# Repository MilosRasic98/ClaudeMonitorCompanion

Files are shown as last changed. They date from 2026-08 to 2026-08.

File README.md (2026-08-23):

# Claude Monitor Companion








A desk mascot that shows what Claude Code is doing.

<p align="center">
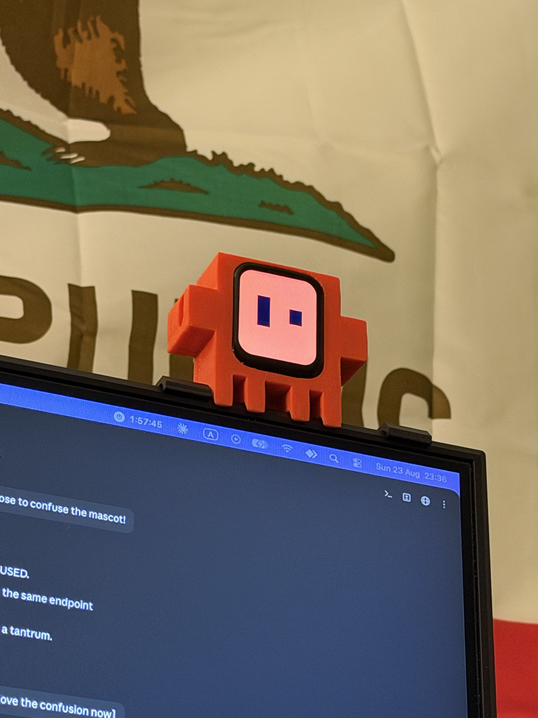
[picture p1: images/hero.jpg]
The mascot hooked over the top of a monitor, eyes lit
  
</p>

A Waveshare ESP32-S3-Touch-LCD-1.69 sits in a 3D-printed shell shaped like the Claude
mascot — the chunky pixel-art crab. The LCD is set into the middle as its face: a flat
orange field with two black bar eyes. The eyes doze when nothing is happening, get bored
when you wander off, focus while Claude works, and snap into a `><` grin the moment Claude
needs you. Hit the five-hour usage limit and the whole screen goes red with a blinking
exclamation mark. A mechanical bell rings for anything that wants your attention.

Claude Code hooks POST bare event names at the board over your LAN. The board decides how it
feels about them.

<p align="center">
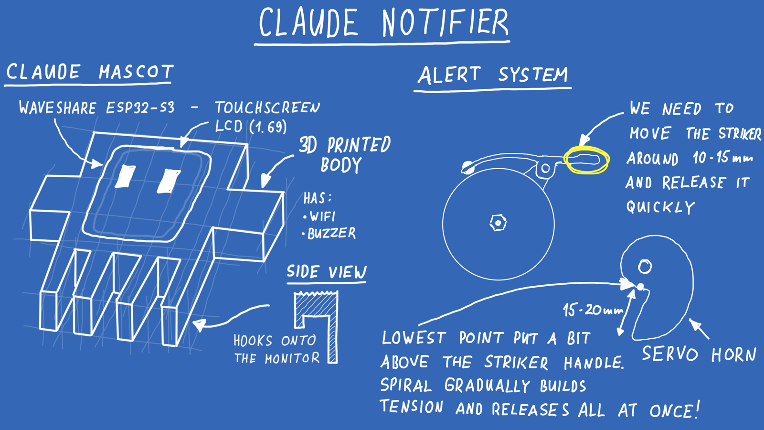
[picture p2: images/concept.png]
Concept sketch of the mascot and the bell striker mechanism
  
</p>

## What it does

### Eight moods

Driven partly by events from your computer, partly by time the board tracks itself.

| Mood | When |
|---|---|
| `SLEEPING` | nothing for ~30 minutes |
| `CHILL` | recent activity, nothing running |
| `BORED` | no new prompt for ~5 minutes |
| `WORKING` | between your prompt and Claude finishing |
| `EXCITED` | Claude needs you, or a turn just finished |
| `CONFUSED` | something failed |
| `ANGRY` | you poked it five times in four seconds |
| `LIMIT` | usage limit reached — red field, blinking `!` |

| | | | |
|:---:|:---:|:---:|:---:|
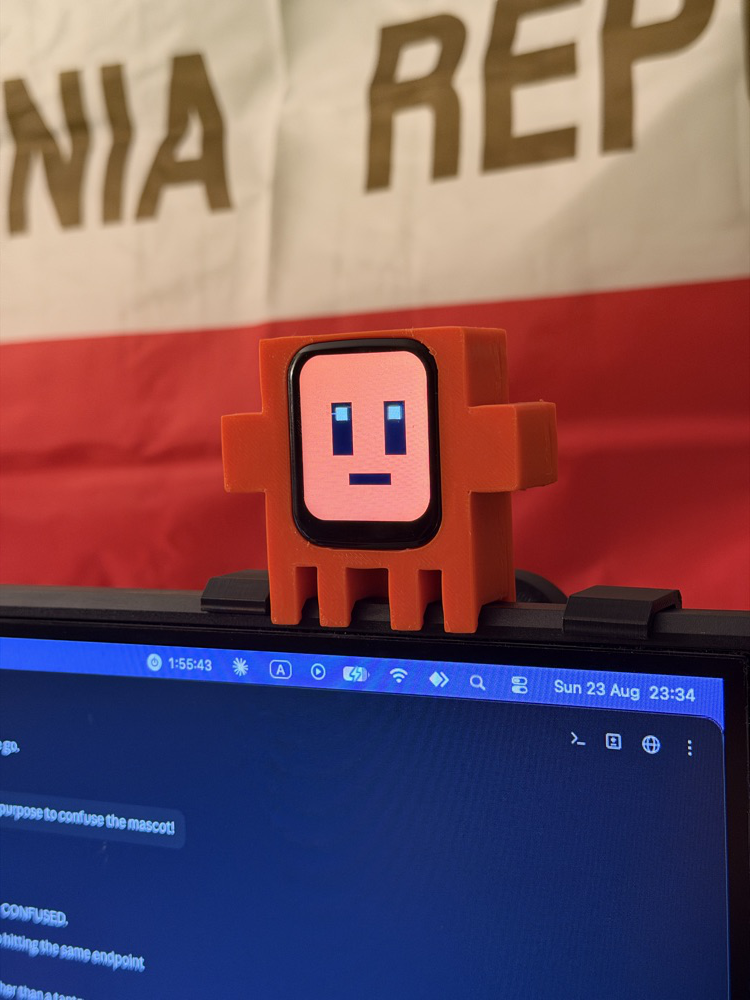
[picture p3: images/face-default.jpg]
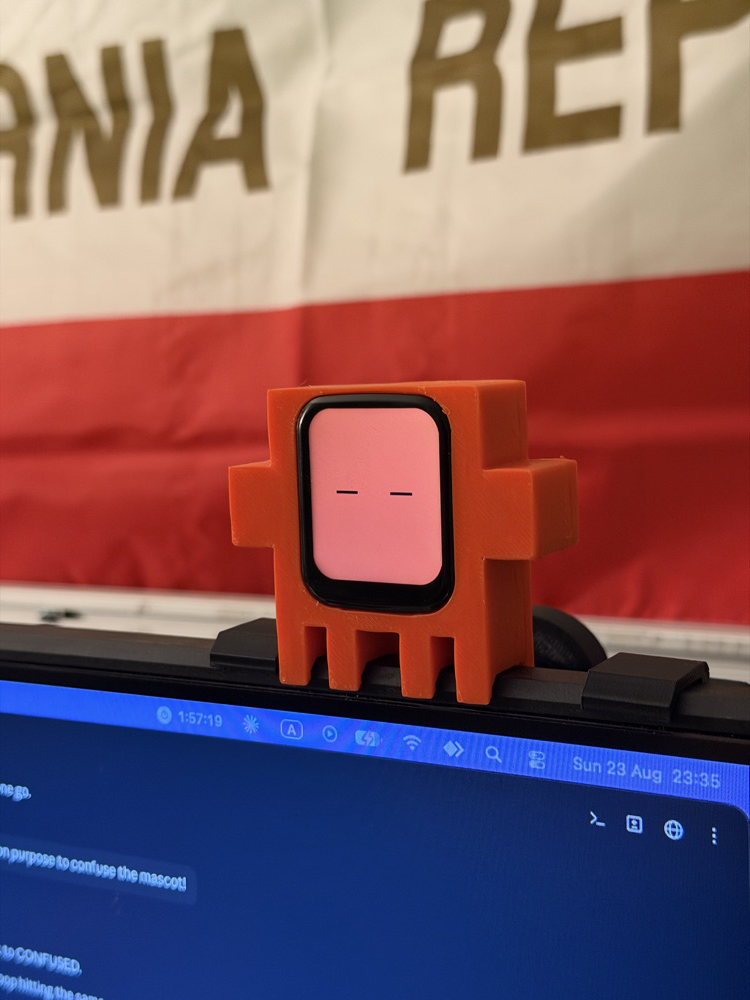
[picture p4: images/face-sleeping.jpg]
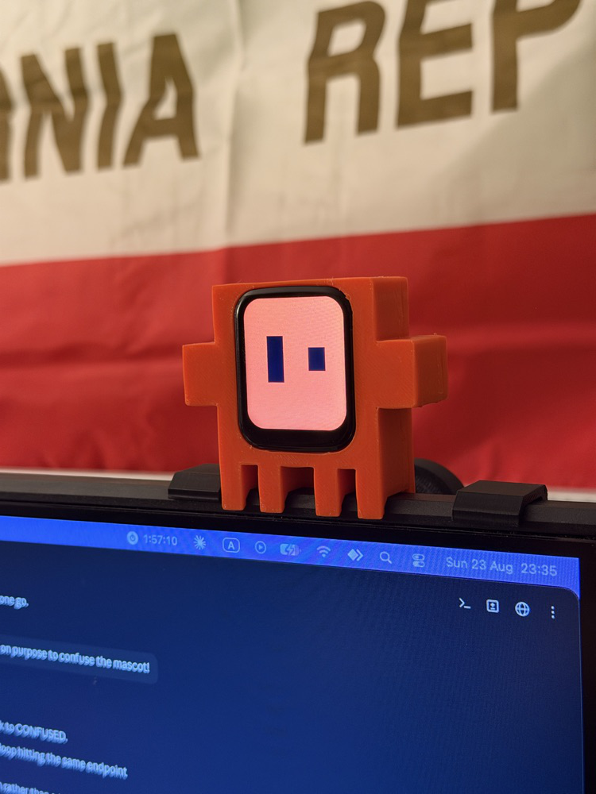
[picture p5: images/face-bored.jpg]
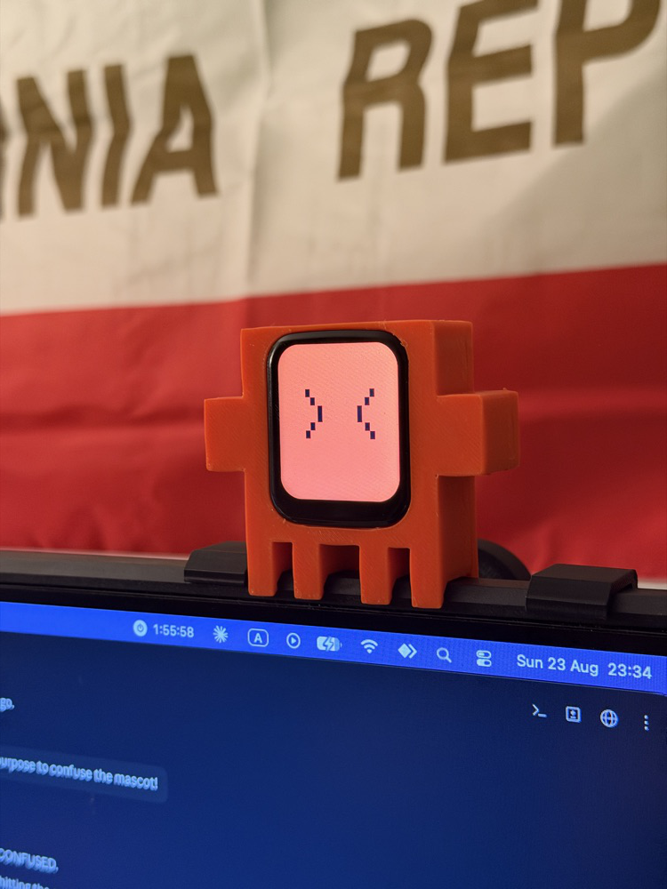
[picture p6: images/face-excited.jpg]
|  |  |  |  |
| **Chill** — resting | **Sleeping** — lids shut, breathing | **Bored** — lids low, gaze adrift | **Excited** — the `><` grin |
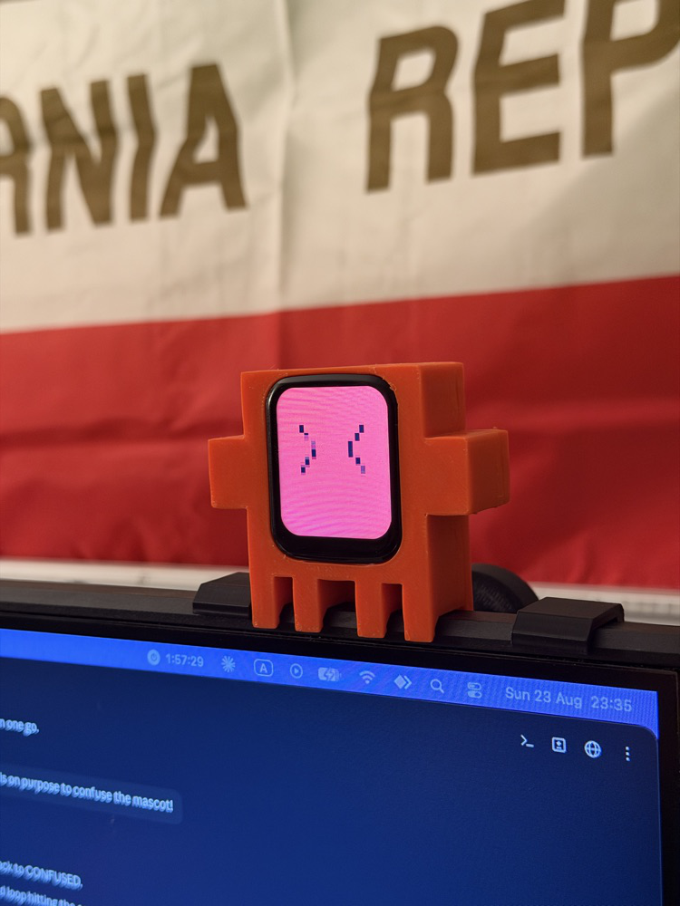
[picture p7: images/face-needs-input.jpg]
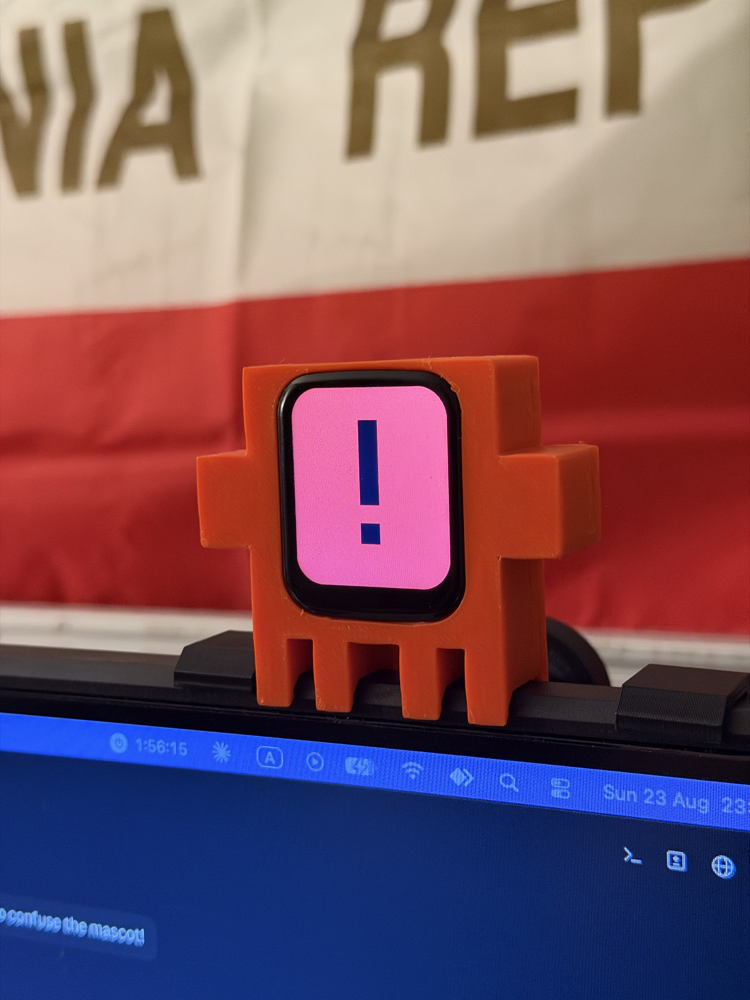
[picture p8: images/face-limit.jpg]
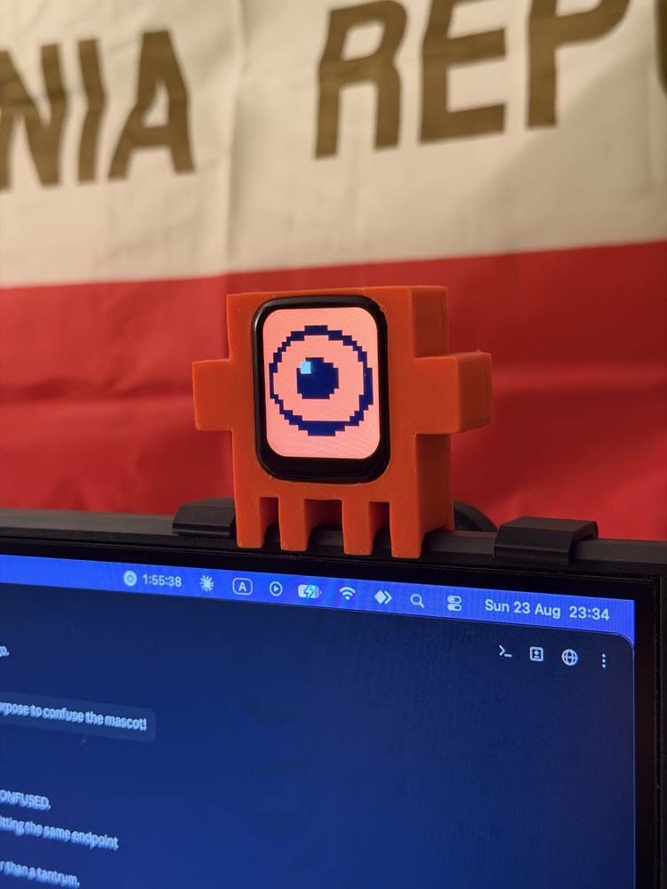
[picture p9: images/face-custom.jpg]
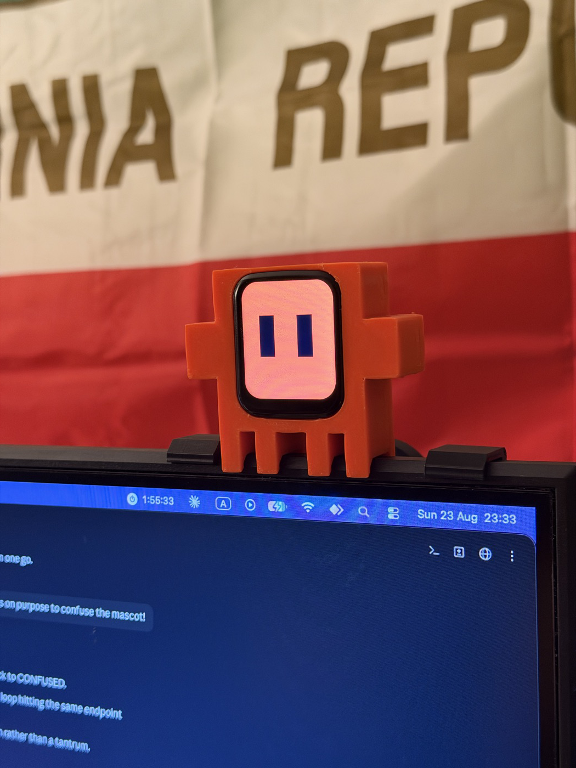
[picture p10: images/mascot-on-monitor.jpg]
|  |  |  |  |
| **Needs input** — red until you answer | **Limit reached** — blinking `!` | **A face you drew yourself** | Perched on the monitor |

Two of those moods — `BORED` and `SLEEPING` — are the *absence* of events. No hook can fire
to say "nothing has happened for five minutes", so the board keeps its own clock. A useful
side effect: the face keeps behaving correctly when the computer sleeps, the Wi-Fi drops, or
Claude Code is closed.

### Five faces, plus four of your own

Taken from the printed mascot's variants: bare eyes, a `><` grin, round spectacles with a
grill mouth, chunky pixel glasses with a smile, and deal-with-it shades with a moustache.
Swipe sideways to cycle them.

| | | |
|:---:|:---:|:---:|
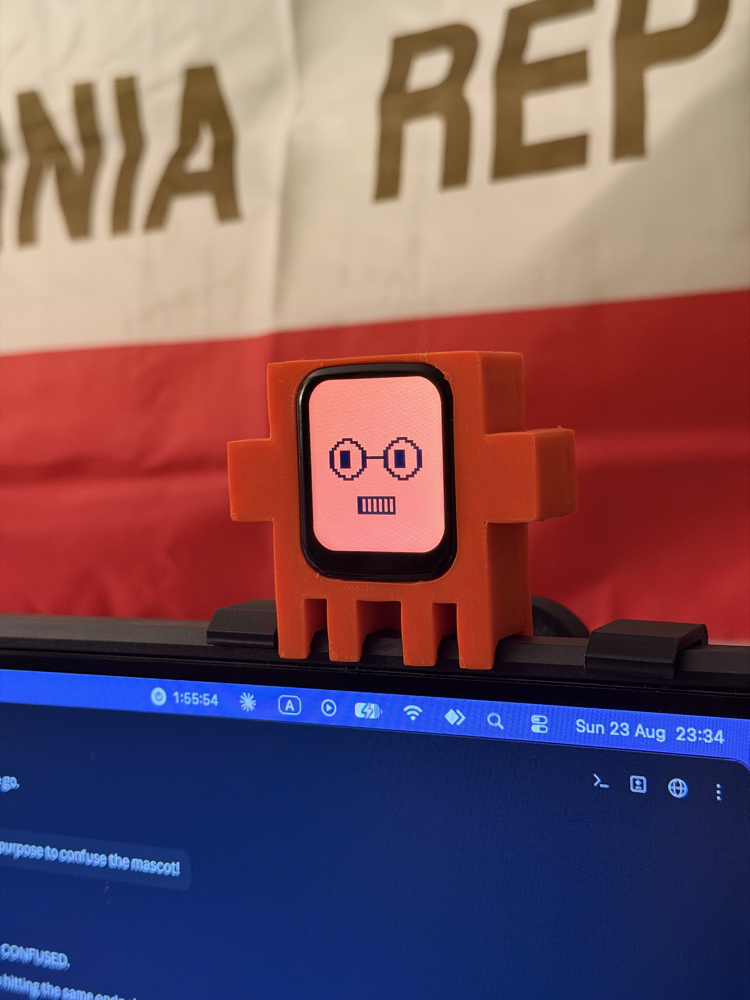
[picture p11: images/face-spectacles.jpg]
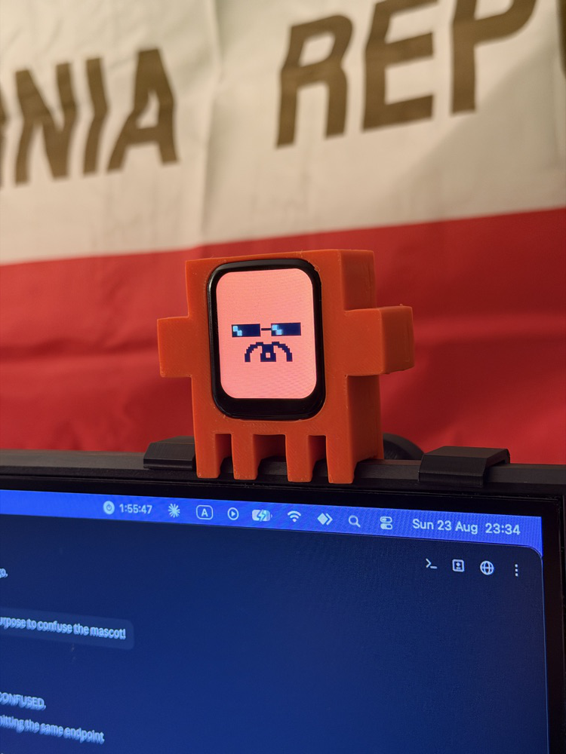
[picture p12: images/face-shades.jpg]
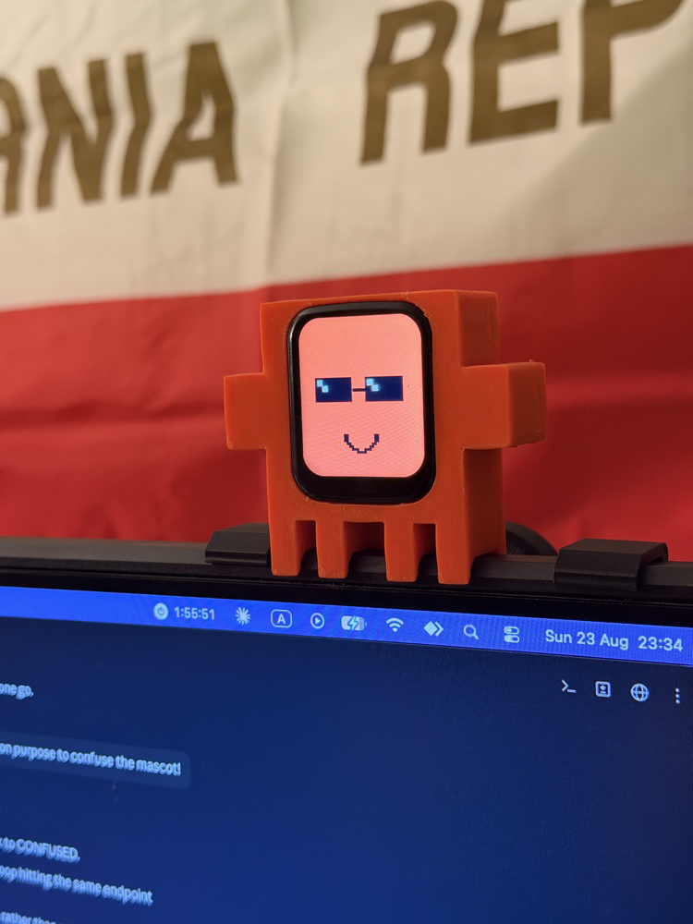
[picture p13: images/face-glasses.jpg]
|  |  |  |
| Round spectacles, grill mouth | Shades and a moustache | Pixel glasses and a smile |

The settings page has a pixel editor. Draw a face on a 24×28 grid, give it a second frame if
you want it to blink, and it joins the rotation — stored in flash, so it survives a reboot.
Drawn faces get the same mood vocabulary as the built-in ones by *translating* within the
frame: the working sweep, the bored droop and the excited bounce all still work.

### Four screens

Swipe up or down for the mascot, a ring gauge showing how much of your five-hour limit is
used and how long until it resets, the same for the seven-day all-models limit, and a plain
stats screen.

### Sound

An optional mechanical bell striker rings for anything that wants your attention, and the
onboard piezo buzzes twice when a turn finishes. Which of bell, buzzer or both fires for each
cue is configurable.

### A settings page, served by the board

Forty-six settings — sound, face geometry, mood thresholds, brightness, Wi-Fi — all editable
from a phone. Flash once and you never open the firmware again. Get the Wi-Fi wrong and the
board hosts its own access point so you can fix it.

## The hardware

<p align="center">
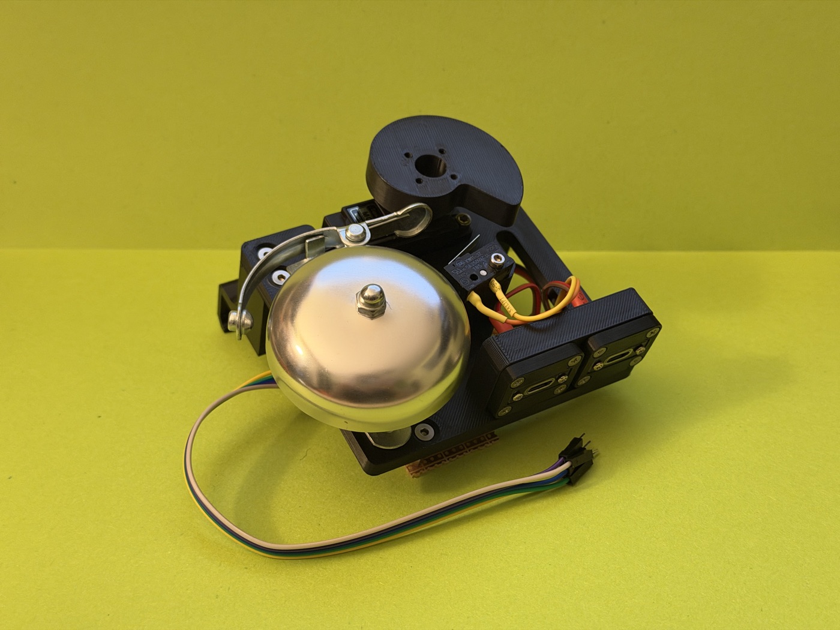
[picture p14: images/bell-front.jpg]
The bell striker assembly
  
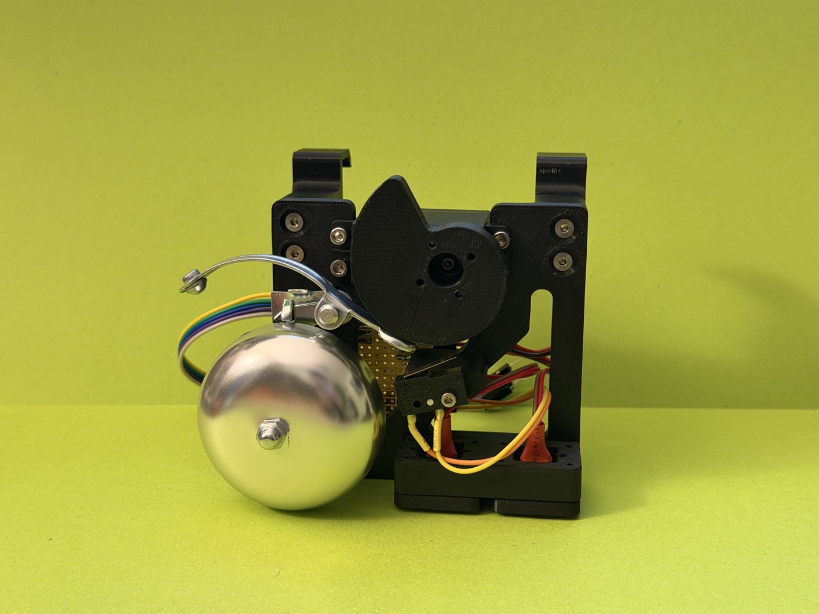
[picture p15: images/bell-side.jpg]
Side view of the servo, cam and bell
  
</p>

The bell is a continuous-rotation servo turning a cam against a desk bell's striker. The cam
gradually builds tension and releases it all at once. A microswitch counts the rings, so the
firmware can stop after a set number of strikes rather than guessing at a duration.

<p align="center">
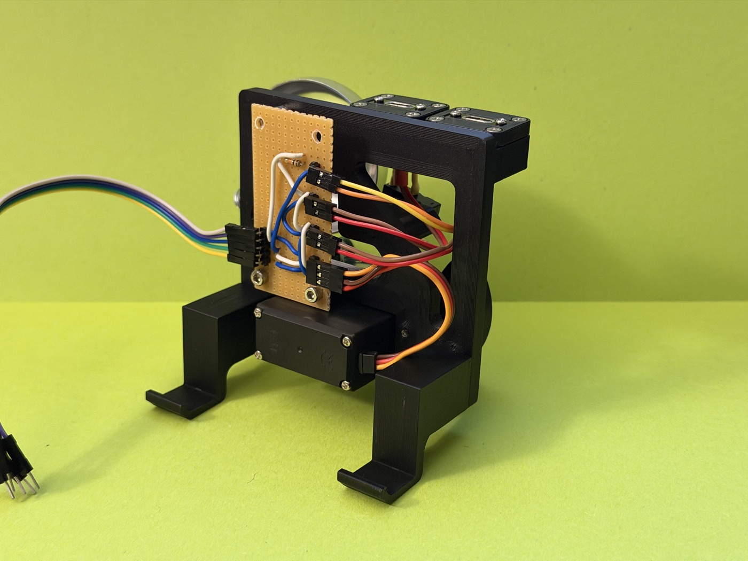
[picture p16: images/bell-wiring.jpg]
Perfboard wiring for the servo and switch
  
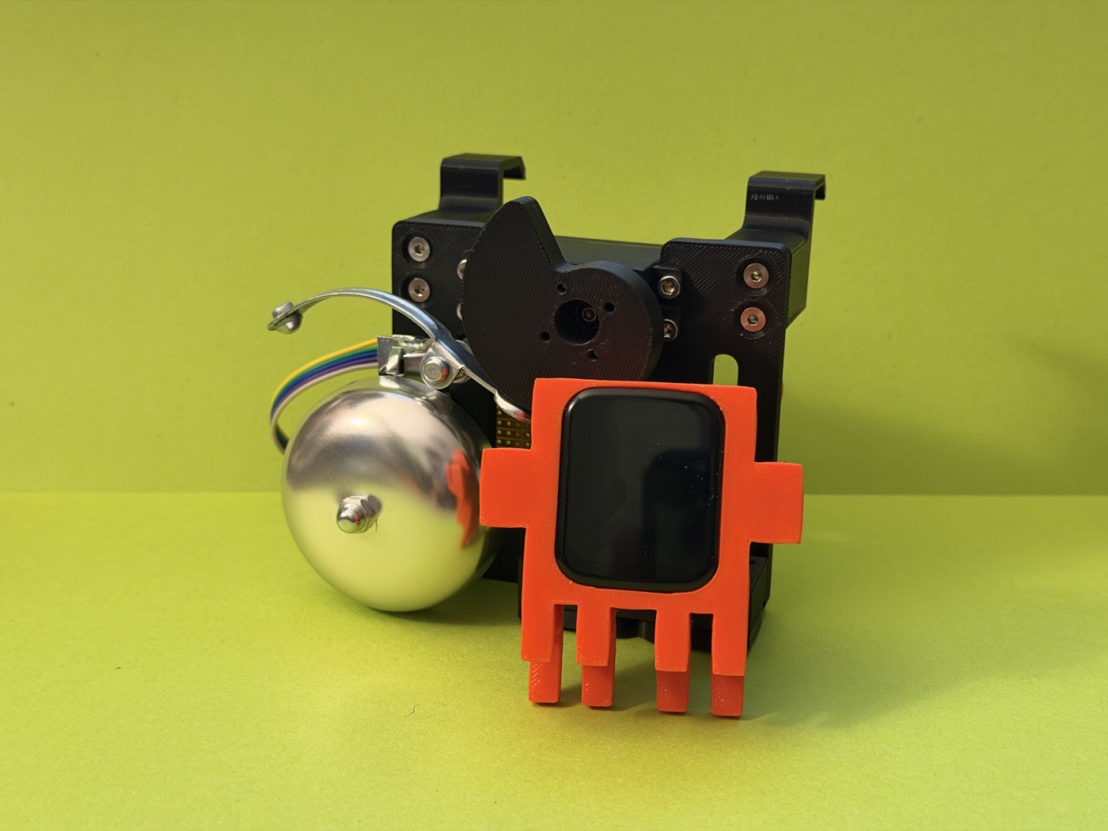
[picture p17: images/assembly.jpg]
Shell and bell mechanism assembled together
  
</p>

| Signal | Pin |
|---|---|
| Servo | GPIO 18 — 50 Hz PWM, 2500 µs runs, 1500 µs stops |
| Microswitch | GPIO 17 — COM to 3V3, NO to the pin, 10 kΩ pulldown |

Both are configurable at runtime; setting either to `-1` disables that half. The bell is
entirely optional — everything else works without it.

Full wiring diagram: **[Hardware/Schematics.png](Hardware/Schematics.png)**. Pin map, measured
performance figures and the traps worth knowing: **[Code/docs/HARDWARE.md](Code/docs/HARDWARE.md)**.

### Bill of materials

| # | Product name | Manufacturer | Qty | Farnell | Newark |
|---|---|---|---|---|---|
| 1 | Continuous servo | Adafruit | 1 | 2816371 | 85W1247 |
| 2 | Microswitch | Multicomp Pro | 1 | 3553972 | 84AH0093 |

Everything else, no particular source needed:

| # | Name | Description |
|---|---|---|
| 1 | Waveshare ESP32-S3 Touchscreen 1.69 | https://www.waveshare.com/wiki/ESP32-S3-Touch-LCD-1.69 |
| 2 | Mechanical bell | |
| 3 | 3D printing filament | |
| 4 | M3 and M2 screws | |
| 5 | Wires and perfboard | |

## The 3D-printed shell

<p align="center">
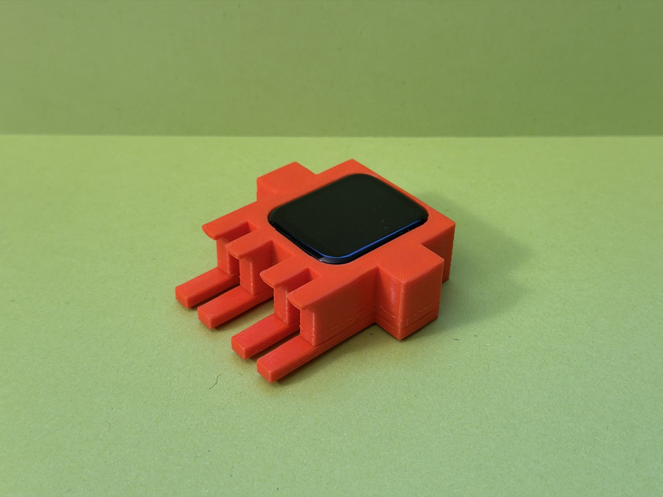
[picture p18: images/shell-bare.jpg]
The bare orange shell
  
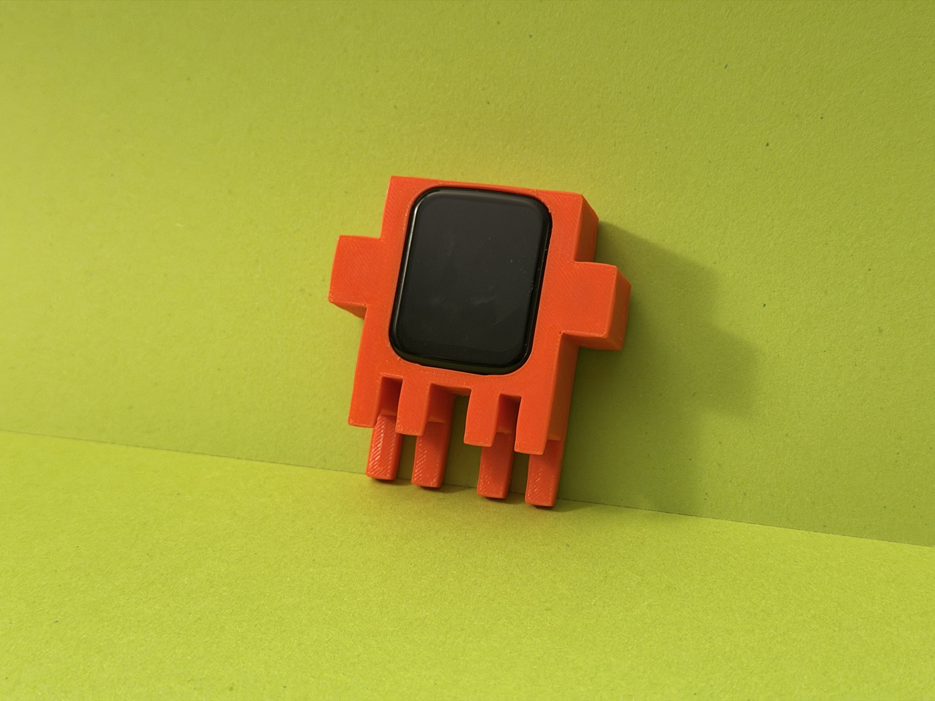
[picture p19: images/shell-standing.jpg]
The shell standing up
  
</p>

Print files are in [`CAD/`](CAD) as both 3MF and STEP: the front and back shells, the monitor
hook, the bell plate, the bell cam and a USB-C plate. Orange for the body, black for the bell
frame.

## How it talks to Claude Code

Claude Code has a feature called **hooks**: entries in its settings file that run a command
when something happens. The command here is literally `curl`.

```json
{
  "type": "command",
  "command": "curl",
  "args": ["-s", "-m", "2", "-X", "POST",
           "-H", "Authorization: Bearer <token>",
           "http://<board-ip>/e/turn_finished"],
  "async": true
}
```

That is the entire mechanism. There are twelve of these and they differ only in the last word
of the URL. Because the event name rides in the URL path there is no body to build, quote or
escape — so no script is needed, and the same config works byte-for-byte on macOS, Windows
and Linux.

**[HOW-IT-WORKS.md](HOW-IT-WORKS.md)** explains the whole thing in a page.

## Platforms

Hooks work everywhere Claude Code runs, including the desktop app: moods, faces, sounds and
the usage-limit alert all come from them.

The two ring gauges need the **CLI**, and specifically the session you are working in. They
are fed by the status line, which the desktop app never runs, and whose figures only refresh
when a session makes API calls — so an idle CLI window parked beside the app reports a frozen
number rather than a live one. The board notices and labels it.

Hooks are exec form and identical on macOS, Linux and Windows. The status line needs a
per-platform script, and the generator emits the right one — Python on Unix, PowerShell on
Windows, where it needs nothing that Windows does not already ship.

## Repository layout

| | |
|---|---|
| [`Code/`](Code) | Firmware. PlatformIO + Arduino, ESP32-S3. Start at [Code/README.md](Code/README.md) |
| [`CAD/`](CAD) | Printable parts, 3MF and STEP |
| [`Hardware/`](Hardware) | Wiring schematic |
| [`images/`](images) | Build and result photos |
| [`HOW-IT-WORKS.md`](HOW-IT-WORKS.md) | How the board and Claude Code actually talk, in a page |

## Quick start

```bash
cd Code
cp include/secrets.h.example include/secrets.h   # first-boot Wi-Fi defaults
pio run -t upload
pio device monitor                               # prints the board's IP
```

Then open that IP in a browser to configure everything else, and wire up the Claude Code
hooks:

```bash
python3 tools/gen_hooks.py <board-ip> <your-token>
```

Merge the output into `~/.claude/settings.json`.
[`Code/docs/settings.example.json`](Code/docs/settings.example.json) shows what that output
looks like, with placeholders in place of the address and token. The full walkthrough,
including why the hook config is shaped the way it is, is in [Code/README.md](Code/README.md).

## Notes on the build

No external libraries. No LVGL, no async web server, no JSON library — just the Arduino core
and the ESP-IDF components it already ships. The face is drawn as quantised rectangles
straight onto the panel, which is both the correct pixel-art look and fast: 62 fps at under
5% of the frame budget.

## Licence

GPL-3.0. See [LICENSE](LICENSE).

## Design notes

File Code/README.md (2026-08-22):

# Claude Monitor Companion

A desk mascot that shows what Claude Code is doing.

A Waveshare ESP32-S3-Touch-LCD-1.69 sits in a 3D-printed shell shaped like the Claude
mascot — the chunky pixel-art crab. The LCD is set into the middle as its face: a flat
orange field with two black bar eyes. The eyes doze when nothing is happening, get bored
when you wander off, focus while Claude works, and snap into a `><` grin the moment Claude
needs you.

Claude Code hooks POST bare event names at the board over the LAN. The board decides how it
feels about them.

- [docs/SPEC.md](docs/SPEC.md) — design, mood engine, open questions
- [docs/HARDWARE.md](docs/HARDWARE.md) — pin map, measured numbers, traps

## Setup

You flash once. After that everything is configured from the board's own web page — Wi-Fi
included — so there is never a second reason to open the firmware.

### 1. Credentials

```bash
cp include/secrets.h.example include/secrets.h
```

Fill in `WIFI_SSID` and `WIFI_PASS`, and set `NOTIFY_TOKEN` to any random string. These are
only the **first-boot defaults**: they are copied into NVS on first run and everything after
that is edited from the settings page. `include/secrets.h` is gitignored.

If you get them wrong, nothing is lost. After four failed joins the board gives up on your
network and hosts its own open access point called `<hostname>-setup`, serving the same
settings page at `http://192.168.4.1/`. Join it from a phone and fix the Wi-Fi there.

### 2. Build and flash

PlatformIO Core lives at `~/.platformio/penv/bin/pio` on this machine and is not on `PATH`.

```bash
~/.platformio/penv/bin/pio run -t upload
```

### 3. Find the board

```bash
~/.platformio/penv/bin/pio device monitor
```

It prints its IP on connect. **Give it a DHCP reservation and use the IP in the hook
config** — on both platforms.

The board does advertise `claude-notifier.local` over mDNS and it resolves fine from a
browser or an interactive `curl`. It is still the wrong choice for hooks: resolution was
measured at **5.1 s per lookup on macOS, uncached**, against the hook's 2 s timeout, so every
hook fails silently. The same request to the raw IP takes **86 ms**. Windows cannot generally
resolve `.local` at all without Bonjour.

Both ends must also be on the **same access point**. Traffic that crosses a range extender's
wireless backhaul was measured at 100% packet loss here; moving the Mac onto the same AP as
the board took it to 0% loss and 27 ms.

### 4. Wire up the hooks

```bash
python3 tools/gen_hooks.py 192.168.1.42 your-token
```

Paste the output into the `hooks` key of `~/.claude/settings.json`. User scope, not project
scope — this is a personal desk peripheral, not something to commit into every repo.

[`docs/settings.example.json`](docs/settings.example.json) is exactly what the generator
prints, with the address and token replaced by `BOARD-IP` and `YOUR-TOKEN`. Read it if you
want to see the shape before running anything; generate the real one rather than editing it
by hand, because it repeats the address twelve times. On Windows the `hooks` block is
byte-identical and only `statusLine.command` differs:

```
powershell -NoProfile -ExecutionPolicy Bypass -File "C:/path/to/Code/tools/statusline.ps1" BOARD-IP YOUR-TOKEN
```

Merge it in rather than overwriting the file — `~/.claude/settings.json` also holds your
theme and notification preferences, and Claude Code will already have written some of it.

Check it works:

```bash
curl -s -X POST -H "Authorization: Bearer your-token" http://192.168.1.42/e/needs_input
```

The face should snap to `><`. Tap the screen to acknowledge.

## Why the hook config looks like that

Two details in the generated config are load-bearing.

**`args` is present, which selects exec form.** Claude Code spawns `curl` directly with no
shell. Without `args` it is shell form, which goes through `sh` on macOS but **PowerShell**
on Windows when Git Bash is absent — and PowerShell aliases `curl` to `Invoke-WebRequest`,
which takes entirely different flags. Exec form is byte-identical on both platforms, and
`curl` ships with macOS and with every Windows version Claude Code supports.

**`"async": true`.** Hook handlers block Claude Code's agentic loop by default, with a 600 s
timeout. A board that is switched off could otherwise stall a session for ten minutes.
`curl -m 2` bounds the network call as well, so dead-board processes cannot pile up.

Together these mean the host needs no script, no runtime, and no compiled helper. That is
only possible because the event rides in the URL path with no request body — which in turn
is only possible because the board owns the mood state machine and the host reports nothing
but raw facts.

## The settings page

Open the board's IP in a browser. Everything is on one page, grouped:

| Group | What you can change |
|---|---|
| **Sound** | piezo on/off, how many buzzes, both tones, volume, both gaps, the bell's GPIO, whether it rings on alerts and on errors |
| **Face** | style, background shade, eye width / height / gap / vertical position, pixel size, blink timings |
| **Timing** | bored-after, asleep-after, celebration length, sulk length, alert timeout, pokes before annoyed, poke window |
| **Screen** | the four backlight levels |
| **Wi-Fi** | network, password, hostname, hook token |

Plus test buttons for the buzzer, the bell and every mood, and a two-step factory reset.

Changes apply immediately — drag the eye width and the face changes as you watch. Only
Wi-Fi settings restart the board.

**The whole thing is table-driven.** One row in [src/app/config.cpp](src/app/config.cpp)
declares a setting, and its storage, validation, JSON and web form all follow from it. The
page renders whatever the board reports, so adding a setting never means editing HTML. Even
the mood test buttons come from a list the firmware publishes.

Some details that matter:

- **Passwords are never sent to the browser.** A blank password field means "unchanged", so
  saving other settings can never wipe your Wi-Fi key.
- **Out-of-range values are rejected, not clamped silently**, and the page reports the
  failure rather than looking like it worked.
- **Editing is not clobbered by the live refresh.** The page polls every few seconds to show
  the current mood and to pick up changes made on the device itself — swiping the style, for
  instance — but it skips any control you are focused on or have unsaved changes in.
- **No authentication.** It is LAN-only, and the bearer token still protects the `/e/*`
  routes a hook uses. Requiring a password to change a buzzer tone would defeat the point.

## Serial commands

The board takes single keystrokes over USB serial, so the animation can be tuned without a
host in the loop.

| | |
|---|---|
| `p` `f` `n` `e` `i` `s` `x` `a` | fire an event: prompt, turn finished, needs input, error, idle, session start/end, ack |
| `1`–`8` | force a mood: chill, working, excited, confused, angry, bored, sleeping, waking |
| `d` | auto-cycle every mood, 5 s each |
| `[` `]` | cycle the face style — same as swiping |
| `c` | cycle the orange candidates |
| `b` | test the bell |
| `w` | scan for 2.4 GHz networks — marks your SSID with `*` and shows its auth mode |
| `h` | health line |
| `?` | help |

Forcing moods matters because `BORED` is five minutes away and `SLEEPING` is thirty.

## Screens

**Swipe up or down** to move between three screens. **Swipe sideways** to change the face's
style, as before. If your panel reports its axes the other way round, flip
`Swap swipe axes` on the settings page rather than rebuilding.

| Screen | What it shows |
|---|---|
| **Face** | the mascot. The resting screen, and what the shell is built around |
| **Gauge** | a ring showing how much of the five-hour limit is used, with time to reset below |
| **Weekly** | the same ring for the seven-day, all-models limit. No countdown — the number is the point |
| **Stats** | IP, signal, uptime, mood, energy, prompts this window, current time |

### Where the gauge's numbers come from

The ring shows the real percentage of your five-hour limit, and the line beneath it the real
time to reset. Both come from Claude Code's **status line**, which is the only place it
exposes them:

```
rate_limits.five_hour.used_percentage    0-100
rate_limits.five_hour.resets_at          unix epoch seconds
rate_limits.seven_day.used_percentage    the all-models weekly limit
rate_limits.seven_day.resets_at
```

There is **no credit or balance figure** anywhere in the status line or the telemetry docs —
`cost.total_cost_usd` is a client-side estimate of the current session only. So there is no
credits screen: an invented number on a dial looks exactly as authoritative as a real one.

**No hook carries this.** The only limit-related hook is `StopFailure` with
`error: rate_limit`, and that fires once you have already hit the wall. So
[tools/statusline.py](tools/statusline.py) reads the status line JSON, forwards those two
numbers to `POST /limits`, and prints an ordinary status line. `gen_hooks.py` emits its
config alongside the hooks.

Two details in that script are load-bearing. The POST is **spawned detached and never waited
on**, because Claude Code cancels an in-flight status line script when a new update arrives —
a blocking call would be killed part-way, and would stall the status bar whenever the board
was off. And the status line **prints regardless** of whether forwarding worked: a desk
ornament must never be able to break the editor it decorates.

Without the status line configured, the gauge falls back to timing the window from the
prompts the board has seen and labels itself `EST - NO HOST`. That fallback is only ever a
lower bound — it cannot know about work done before the board was switched on, so it reads
the window as opening later than it really did. This is why the fallback is labelled rather
than dressed up as a quota.

Wall-clock time comes from NTP through the POSIX timezone string in settings. Until the first
sync the gauge reads `NO CLOCK` rather than guessing.

### Platform notes

The two halves are portable to different degrees, and it is worth knowing which is which.

**The hooks are genuinely OS-independent.** They use exec form — `command` plus an `args`
array — so Claude Code spawns `curl` directly with no shell involved: no quoting rules, no
PATH surprises. `curl` ships with macOS, with Windows since 1809 (which is below Claude
Code's own minimum), and with essentially every Linux. The same block works byte-identically
on all three. Moods, faces, the red field, the exclamation mark and the sounds are all on
this side.

**The status line is not.** `statusLine` takes only a `command` string — there is no `args`
field, so it is always run through a shell, and a different shell on each platform. Hence two
scripts:

| | Script | Needs |
|---|---|---|
| macOS, Linux | [tools/statusline.py](tools/statusline.py) | `python3` on PATH |
| Windows | [tools/statusline.ps1](tools/statusline.ps1) | nothing beyond what Windows ships |

The PowerShell version exists because Python is *not* dependable on Windows — it is usually
`python` rather than `python3`, and the Microsoft Store stub hijacks the name — whereas
PowerShell always is. It parses the JSON with `ConvertFrom-Json` and posts with `curl.exe`,
both built in.

Two Windows details the generator handles for you, and which are easy to get wrong by hand:
the script path must use **forward slashes**, because Claude Code routes the status line
through Git Bash when it is installed and Git Bash silently eats backslashes in a Windows
path; and the path is **double quoted**, so a space in it does not split the command.

**The status line only runs in the CLI.** The desktop app has no status bar, so it never
invokes the command — confirmed by instrumenting the script and watching a full
`refreshInterval` pass with zero calls.

**And it must be the session you are actually working in.** A Claude Code session refreshes
its rate-limit snapshot from API responses, so an *idle* session forwards the same figure
forever, punctually, while the real work happens elsewhere. Parking an idle CLI window next
to the desktop app does not work: the gauge looks live, because reports keep arriving on
time, while the number is frozen. That is worse than showing nothing.

The board detects it. The hooks keep telling it prompts are being submitted, so if five
prompts arrive with no change in the reported percentage, the gauge labels itself
`PCT STALE` and `/api/config` reports `limit_suspect: true`. Five prompts is comfortably more
than a percentage point of a five-hour budget, so an unchanged figure across that many is not
plausible.

So: **use the CLI as your main interface if you want the gauges live.** If you prefer the
desktop app, remove the `statusLine` entry — the board then falls back to its own elapsed-time
estimate and labels it `EST NO HOST`, which is honest about being an estimate.

**`statusLine` is read when a session starts.** Hooks hot-reload when you edit settings, the
status line does not — after changing it, restart the session or it keeps running the old
command.

The gauge shows `EST NO HOST` until the first report arrives, and `device.limit_age_s` on
`/api/config` reads -1 until then. That is the quickest way to tell "not running" from
"nothing has changed", and `MASCOT_DEBUG=1` on the status line command logs every invocation
and its payload to `~/.claude/mascot-statusline.log` when you need to know which.

### How often it refreshes

The percentage comes from the host, so it updates whenever the status line runs: on every
assistant message, and at least once a minute via `refreshInterval`. Claude Code debounces
those at 300 ms.

The countdown does not depend on the host at all. `resets_at` is an absolute epoch, so once
the board has it, NTP time is enough to tick the remaining time down every minute — even
with Claude Code closed.

### Drawing a smooth ring cheaply

The ring is a real circle, not a ring of blocks. The two costs are worth separating: testing
every pixel in the bounding box is a few thousand float operations and costs nothing, while
one SPI transaction per pixel would be ruinous. So each row is scanned, runs of identical
colour are coalesced, and one rectangle is pushed per run — a few hundred transactions for
the whole ring, and only when the value changes.

The unfilled part of the track is the background colour darkened at runtime, so it reads
correctly on the orange field and on the red alert field without a second hardcoded colour.

Everything else — the percentage, the countdown, the face — stays on the pixel grid. The
ring is the one place a curve beats blocks, because a dial has to be readable at a glance
from across a desk.

## Faces

The printed mascot exists in several faces, so the firmware does too. **Swipe across the
screen** to cycle them, or `[` and `]` over serial. The choice is saved to NVS and survives
a reboot.

Swipes are derived from the raw coordinate stream, not from the CST816's own gesture
register. The chip only decides a gesture happened once the finger lifts, and it latches the
code afterwards — so a second swipe the same way reads as unchanged and gets dropped, which
is exactly the motion you make flicking through styles. Watching coordinates instead means
the swipe fires the moment it crosses the threshold, mid-drag. Thresholds are `SWIPE_MIN_PX`
and friends in `tuning.h`; sampling runs at 5 ms.

| Style | On screen |
|---|---|
| `plain` | two bar eyes, nothing else — the default character |
| `grin` | `><` chevrons, always, regardless of mood |
| `round` | round spectacles with a bridge, pupils animating inside them, barred grill mouth |
| `pixel` | chunky rectangular glasses with white glints, open smile |
| `shades` | deal-with-it sunglasses and a handlebar moustache |

Style is a costume; mood is the expression underneath. Both apply at once — a bored mascot
in shades is still bored, it just shows it differently.

That last part is why the opaque styles work at all. When the lenses hide the eyes, the mood
has nowhere to go, so the glasses inherit the motion instead: they bounce when excited and
droop when bored. The eyes are pinned still in those styles precisely so the accessories can
carry it.

Spectacles are the other interesting case. The eyes shrink to pupils and their travel is
penned inside the lenses, but a blink still scales proportionally, so it reads as a blink at
pupil size rather than a clipped version of the full-size one.

Accessories are static art, drawn once when the style changes and again only when they move.
Curves — the lens rings, the smile, the moustache — are drawn one grid row at a time, so a
circle comes out as a staircase. That is the point.

## Which hooks drive what

| Hook | Matcher | Board event | Face |
|---|---|---|---|
| `UserPromptSubmit` | — | `prompt_submitted` | `WORKING` |
| `PermissionRequest` | — | `needs_input` | **red, sticky** |
| `PreToolUse` | `AskUserQuestion\|ExitPlanMode` | `needs_input` | **red, sticky** |
| `PostToolUse` | `AskUserQuestion\|ExitPlanMode` | `answered` | back to `WORKING` |
| `Notification` | `permission_prompt` | `needs_input` | **red, sticky** |
| `Notification` | `idle_prompt` | `idle` | `CHILL` |
| `Stop` | — | `turn_finished` | `EXCITED`, 6 s |
| `PostToolUseFailure` / `StopFailure` | `*` / — | `error` | `CONFUSED` |
| `SessionStart` / `SessionEnd` | — | session lifecycle | — |

**`PermissionRequest` is the one that matters** for "Claude is waiting on me". The docs are
explicit that it is narrower than `PreToolUse`: it fires *only* when Claude Code is about to
show a permission dialog, not before every tool call. So it costs nothing when nothing is
being asked. `Notification`/`permission_prompt` covers the same ground but ~6 s later; it is
kept because re-asserting the same state is harmless and it catches anything the first one
misses.

`PreToolUse` matches on tool name, so scoping it to `AskUserQuestion` and `ExitPlanMode` —
the two tools whose entire purpose is asking the user something — means no other tool call
ever spawns a process.

`needs_input` deliberately does **not** clear the running-turn flag: a permission prompt
happens *during* a turn, so answering it returns the face to `WORKING`, not `CHILL`. The
paired `PostToolUse` hook is what clears it. A sticky alert also self-expires after
`ALERT_MAX_MS` as a safety net, so a missed clear can never strand the face red.

## Drawing your own face

The settings page has a pixel editor. Four slots, 24 x 28 cells each, at ten screen pixels a
cell — exactly 240 x 280, so what you draw is literally what appears, with no scaling.

Three inks: black, white and erase. White because the built-in sunglasses use it for lens
glints, and a custom face should be able to do the same.

Each slot has **two frames**, resting and blink. A static face would sit visibly dead next to
the built-in ones, which all blink, and one extra frame is the cheapest animation there is.
There is a "copy resting to blink" button because a blink is almost always the resting face
with the eyes closed. Leave the blink frame empty and the face simply does not blink.

**Only slots with something drawn join the swipe rotation**, so empty ones are never dead
screens. Clearing a slot drops it back out. Occupancy is judged from the resting frame alone.

Saved to NVS, one key per slot so saving one face does not rewrite the others, and written
once when you press save rather than on every stroke — flash write cycles are finite. It
survives reboots and reflashing, since flashing does not erase the NVS partition.

**A drawn face animates too.** It cannot change shape the way the parametric eyes do, but it
can move, and moving carries most of the expression. The whole drawing translates within the
panel and the background fills whatever the shift vacates — so it sweeps while Claude works,
droops and looks aside when bored, bounces when excited, shakes off a poke, and breathes
slowly while asleep. Exactly the same mood vocabulary as the built-in faces, with no extra
frames to draw.

Motion is in whole cells. The art is ten-pixel blocks, so a ten-pixel step is what keeps it
reading as the same object moving, rather than a bitmap sliding underneath a grid. Amplitudes
are `CUSTOM_*_CELLS` in [tuning.h](include/tuning.h).

Only cells that differ from what is already on screen get redrawn, so a one-cell drift or a
blink is a handful of rectangles rather than 672.

## Mood model

Two inputs: events pushed from the host, and time the board tracks itself.

| Mood | Enters when | Eyes |
|---|---|---|
| `SLEEPING` | nothing for ~30 min | closed to flat bars, slow breathing drift |
| `WAKING` | first event after sleeping | bars grow with a slight overshoot |
| `CHILL` | recent activity, nothing running | full bars, random blinks, slow drift |
| `BORED` | no new prompt for 5 min | 60% height, drooped and looking away, long blinks |
| `WORKING` | between prompt and turn finished | full height, sweeping left-right scan |
| `EXCITED` | needs input, or turn finished | `><` chevrons, bounce, bell |
| `CONFUSED` | a turn failed | one eye squinting, slow shake |
| `ANGRY` | poked five times in four seconds | one fixed set of slanted brows, red field |

**The field turns red whenever the mascot wants something** — an unacknowledged `needs
input`, or a fit of pique. Visible across a room, and it does the bell's job until the bell
exists. A finished turn does *not* go red: that is a celebration, not a demand.

**Poke it and it shakes the poke off.** Every tap runs a fast head-shake over whatever mood
is playing. Keep poking — five taps inside four seconds — and it snaps to `ANGRY`: one fixed
set of slanted brows, no animation, red background, seven seconds to cool off. Boredom and
sleep are suppressed while it sulks.

`BORED` and `ASLEEP` cannot come from hooks — `idle_prompt` fires once and never repeats,
and nothing fires at all when Claude Code is not running. They are elapsed-time decay on the
board, which is also why the face keeps behaving when Wi-Fi drops.

Alerts are sticky. `needs_input` waits to be acknowledged; boredom and sleep are suppressed
until it is, so something you still have to deal with never quietly turns into a yawn. A
finished turn is a six-second celebration that decays on its own.

**Energy** is a separate 0–100 value that decays continuously and is bumped by every event.
It modulates blink rate, sweep speed and bounce amplitude *within* a mood, so a quiet
afternoon and a heavy refactor look different even when both are nominally `WORKING`.

## Tuning the face

Everything lives in [include/tuning.h](include/tuning.h): palette, grid quantum, eye
geometry, per-mood motion amplitudes, mood thresholds, energy rates, backlight levels. One
edit and a reflash. Nothing is hardcoded elsewhere.

`GRID_Q` is the interesting one. Every coordinate is snapped to it, which is what makes the
motion step like pixel art instead of gliding. It also sets how many distinct steps a blink
has — about 20 at the current 5 px, which reads as deliberate. At 10 px it would be 10,
which reads as broken.

## Performance

Measured on the actual board, 240x280 at 80 MHz SPI:

| | |
|---|---|
| Frame rate | 62 fps, held during a Wi-Fi association retry storm |
| Frame cost, `CHILL` / `BORED` / `CONFUSED` | 78–160 µs |
| Frame cost, `EXCITED`, bare eyes | 703 µs |
| Frame cost, `EXCITED`, accessory styles | 0.6–2.0 ms |
| Full-screen fill | 18.6 ms |
| Flash / RAM | 12.5% / 14.6% |

Under 5% of the 16 ms frame budget at worst. Three things get it there: only the pixels that
actually changed are pushed, rendering runs in its own task on core 1 while Wi-Fi stays on
core 0, and every solid colour has its own pre-filled DMA buffer so transfers pipeline
without ever waiting.

## Dependencies

None. No LVGL, no ESPAsyncWebServer, no JSON library, no vendor SDK — just the Arduino core
and the IDF components it already ships.

## Sound

Two separate noises, deliberately.

Three cues, and you choose independently for each whether it uses the striker, the buzzer,
both, or nothing:

| Cue | When |
|---|---|
| **Blocked** | anything that turns the field red — a permission prompt, a question, being poked past patience, or hitting the usage limit |
| **Error** | a tool call or a turn failed |
| **Finished** | a turn ended normally |

Not everyone wants to build a mechanical bell, so the buzzer alone covers all three.

**The buzzer has two shapes, not two pitches.** Good news is a short rising double chirp,
2.7 kHz then 3.5 kHz, repeated so it lands as *buzz buzz*. Bad news is one long 650 ms tone.
Different shapes rather than different notes, so you can tell them apart with your back to
the desk. A long buzz never repeats — that would be alarming rather than informative.

Press `z` for the short one and `l` for the long one, or use the test buttons on the settings
page.

`PIEZO_REPEATS` in `tuning.h` sets how many times; `PIEZO_REPEAT_GAP_MS` is deliberately
wider than the gap inside the pattern, so it reads as two buzzes rather than four beeps.

That second one looks like it contradicts the "hold the piezo low" rule, and does not. The
hazard is the pin *idling* high or floating, which makes a passive buzzer draw current
continuously and cook the LDO. Driving it briefly is what it is for. Every path out of the
chirp sequence — including the gap between the two beeps and the end — goes through
`piezo_silence()`, which parks the duty at zero. It uses `ledc_set_duty(0)` rather than
`ledc_stop()` because stop disables the channel and the next chirp would have to re-enable
it.

Three LEDC timers, one each for backlight, striker and piezo. Channels sharing a timer
corrupt each other's frequency, and the piezo changes frequency mid-sequence.

### The servo is released, not held

A continuous-rotation servo does not move without a signal, so the bell cuts the PWM and
parks the pin low when idle rather than holding a neutral pulse. Holding neutral keeps the
servo drawing current, and if its neutral trim is even slightly off it creeps forever — in a
sealed case, next to the antenna, for no reason.

The servo is also attached on demand rather than at boot, so start-up and joining the network
happen with it completely inert.

## Wi-Fi troubleshooting

The board supervises its own reconnection: `setAutoReconnect()` stops trying after enough
failures, which leaves the board offline forever with nothing in the log. Every
`WIFI_RETRY_MS` it tears the association down and starts again, logging the attempt.

Press `w` for a scan. It disconnects first — scanning mid-handshake returns an empty list
that looks like "no networks" and is not — then lists what it can see, marks your SSID with
`*`, and prints each network's auth mode. Read the disconnect reason alongside it:

| Reason | Means |
|---|---|
| `201 NO_AP_FOUND` | SSID not visible. Usually a 5 GHz-only network — the ESP32-S3 has no 5 GHz radio |
| `202 AUTH_FAIL` | AP rejected the key. Wrong password |
| `15 4WAY_HANDSHAKE_TIMEOUT` | Handshake started and stalled. Wrong password, or WPA3/PMF required |

If the password contains a backslash or a double quote it must be escaped in `secrets.h` —
it is a C string literal, so `\` and `\"`.

## Verified on hardware

Everything below was measured on the real board, not inferred.

| | |
|---|---|
| HTTP endpoints | 12/12 — every event route, plus 401 on missing/bad token, 404 on unknown event and on the wrong verb |
| Link reliability | 20/20 single-shot, once both ends share an access point |
| Hook argv | 8/8 fire, 43–166 ms each, using the exact `command` + `args` Claude Code will execute |
| Face | all eight moods, all five styles, red alert field, angry face, poke shake |
| Render | 62 fps sustained, 78 µs–2 ms per frame, held through a Wi-Fi retry storm |

## Not done yet

- The mechanical bell. An external striker on LEDC PWM; the actuator, drive stage and GPIO
  are undecided, so `PIN_BELL` is `-1` and `bell::strike()` logs instead. Everything that
  should ring it is already wired — see Sound below.
- Eye geometry is placeholder until the shell's screen cutout is measured.
- Which of the four orange candidates matches the filament.
- Touch coordinate orientation is unverified against a real finger.
- `tools/statusline.ps1` has been written and reviewed but never executed — it was developed
  on a Mac with no PowerShell available. The logic mirrors the Python version, which is
  tested, but treat the first Windows run as the real test. Swipe cycling keys off
  whichever axis dominates, so a horizontal flick works even if the driver's axes turn out
  swapped; only the direction could need flipping, via `SWIPE_INVERT`.
- Hats are not rendered. The top hat and the sailor hat in the reference photos sit above
  the head, outside the screen cutout — they belong to the printed shell, not the firmware.

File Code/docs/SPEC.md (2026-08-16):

# Claude Monitor Companion — draft spec

Status: **built and running on hardware.** Everything below is implemented except the bell,
which is blocked on hardware decisions. Items marked ❓ are still open. Setup and usage:
[README.md](../README.md).

Two things were learned on hardware that are worth carrying forward:

- `esp_lcd_panel_draw_bitmap()` is asynchronous. Rewriting a shared strip buffer between
  calls corrupts the transfer still in flight, which showed up as eyes visibly tearing apart
  during sideways movement. Fixed by giving each solid colour its own pre-filled DMA buffer
  so nothing is ever mutated mid-flight. That also removed the need to block per transfer:
  worst-case frame cost fell from 2.9 ms to 0.7 ms.
- The core-separation bet paid off. With the board stuck in a Wi-Fi association retry storm
  on core 0, the render task on core 1 held 62 fps throughout.

## What it is

A small mascot head that sits on top of a monitor. The 240x280 screen is its **face** —
two animated eyes and a few accents. The face mirrors what Claude Code is doing on the
computer: dozing when nothing is happening, bored when you have wandered off, focused
while Claude works, and visibly thrilled the moment it needs you.

It is an ambient-presence object first and a notifier second. The animation quality is
the product. A dashboard that happened to have eyes would be the wrong build.

## The mood engine

Two inputs drive the face:

1. **Events** pushed from the computer when something happens in Claude Code.
2. **Time**, which the board tracks itself.

That split matters: "bored" and "asleep" are the *absence* of events, so the board has to
own the state machine. The host only reports facts; the board decides how it feels about
them. This also means the face keeps behaving correctly if the host goes quiet, sleeps, or
the Wi-Fi drops.

### Moods

| Mood | Enters when | Face |
|---|---|---|
| `SLEEPING` | no event for ~30 min ❓ | eyes closed to a curved line, slow breathing bob, occasional drifting Z |
| `WAKING` | first event after sleeping | lids crack open, one stretch, settles into `CHILL` |
| `CHILL` | recent activity, nothing running | eyes open, random blinks every 2–6 s, slow saccades, micro-drift |
| `BORED` | awake, no new user prompt for 5 min ❓ | lids droop, pupils drift off to one corner, periodic yawn, long slow blinks |
| `WORKING` | Claude is actively running | pupils scan in a repeating sweep, slight concentration squint, faster blink |
| `EXCITED` | Claude needs the human — waiting on input, or turn finished | eyes wide, pupils dilate, vertical bounce with overshoot, sparkle accent, one bell strike |
| `CONFUSED` | a turn failed | one eye squints, brow angles in, slow horizontal head-shake |

### Energy

A `0..100` scalar, separate from mood. Each event bumps it; it decays continuously toward
zero. This is the "how hard is Claude being used right now" signal, and it modulates the
face *within* a mood rather than switching moods:

- blink rate and saccade frequency
- animation playback speed
- pupil size (bigger when energised)
- how emphatic the `EXCITED` bounce is

So a quiet afternoon of one-off questions and a heavy refactor session look different even
when both are nominally `WORKING`.

### Touch

Tap the face and it reacts — a happy blink, pupils snap to the touch point. Tapping while
`EXCITED` also acknowledges the alert and silences the bell. Petting the thing should feel
like it does something. ❓ Should tap-to-ack be the only way to clear an alert, or should
it also clear on the next event from the host?

## Physical form

A 3D-printed shell in the outline of the Claude mascot — the little pixel-art crab — with
the LCD set into the middle as its face. The screen therefore shows **only** a flat orange
field with black eyes on it. The body, claws, and silhouette are plastic, not pixels.

Consequences for the firmware:

- The LCD's rounded corners get hidden behind the shell's cutout, so the full rectangle is
  usable and nothing has to dodge the corners.
- ❓ The cutout's shape and size are unknown. Eyes should be laid out around the screen
  centre with a generous safe margin until it is measured.
- ❓ The on-screen orange has to relate to the filament colour — either matched so the face
  reads as one surface, or deliberately brighter so it glows against the shell. Needs a
  physical sample to judge; the value lives in `tuning.h` either way.

## Face construction

Reference: photos of the printed mascot. Established from them —

- The body is flat, saturated orange. The eyes are flat black. Two colours, no gradients,
  no outlines, no shading.
- The **default face is two tall narrow black rectangles**, roughly 1:3 width to height,
  separated by about two eye-widths, sitting slightly above centre.
- A canonical alternate face exists: **`>` `<` chevron eyes**, inward-pointing, chunky and
  stair-stepped. That is the happy/squint variant.
- No mouth in the default form. The versions with smiles, mustaches, tophats and sunglasses
  are physical accessories clipped onto the print, not part of the base character.

So the confirmed on-screen job is: **an orange field with two black rectangles that change
shape.** That is a much smaller problem than the animated-eyeball design this spec started
with, and it settles the renderer.

### Parametric shapes, rasterised to a quantised grid

An eye is a rectangle with four animated parameters: height, width, vertical offset, and
horizontal offset. A blink is height going to near-zero and back. Droop is height down plus
offset down. Everything that interpolates is expressed this way — no sprite sheet needed for
the common case.

The 8-bit look comes from **snapping every coordinate to a grid quantum** — proposed **5 px**
— before drawing. Motion then steps in visible increments exactly like the printed character.

**Quantum choice matters more than it sounds.** It sets how many distinct steps a blink has:
an eye about 100 px tall gives ~20 steps at a 5 px quantum, ~10 at 10 px. Ten reads as janky,
twenty reads as deliberate. Starting at 5 px, and it is one constant.

### Getting pixels to the panel

Naive approaches both lose, for reasons that are specific to this face:

- **One SPI transaction per changed cell** is catastrophic. A 10 x 10 cell is 200 bytes —
  20 µs of payload against roughly 45 µs of CASET + RASET + RAMWR overhead, so 69% of the
  time is command overhead. Pushing every cell individually costs more than blitting the
  entire screen.
- **A single coalesced bounding box** fails on this specific layout. The two eyes sit at
  opposite sides of the screen, so their union spans nearly the full width and the box is
  most of the frame.

What works: rasterise the parametric shapes into a small logical grid, diff it against the
previous frame, and **for each changed cell-row emit its contiguous changed spans** — two per
row for two eyes, skipping the gap between them. If a row somehow needs more than two spans,
coalesce it to one full-width strip rather than spraying transactions.

A 30 px wide span over a 5 px row is about 75 µs all-in, so a blink touching ~20 rows costs
roughly 3 ms against a 16 ms frame budget. Full screen at 80 MHz is 13.4 ms, so this leaves
4x headroom and the budget goes on animation quality instead of throughput.

Grid at a 5 px quantum is 48 x 56 cells = 2,688 bytes, times two for the previous-frame copy.
Plus a double-buffered strip. Everything stays in internal SRAM; PSRAM never enters the
render path.

### Driver and threading

- **esp_lcd directly**, with `trans_queue_depth = 10` and the `on_color_trans_done` callback.
  Available under Arduino-ESP32 3.x by including the IDF headers; use `SPI2_HOST` and never
  call `SPI.begin()`. The callback fires in ISR context — notify a task, do no work there.
  Arduino_GFX's `Arduino_ESP32SPIDMA` backend is an acceptable fallback for ergonomics; plain
  `Arduino_ESP32SPI` is not, because it busy-waits with no DMA.
- **Render task pinned to core 1**, priority 3, 4 kB stack, paced with `vTaskDelayUntil` on a
  16 ms period so jitter cannot accumulate. Not serviced from `loop()`.
- **All Wi-Fi and HTTP on core 0**, which is where Arduino-ESP32 pins the Wi-Fi task anyway.
  The Wi-Fi driver runs at priority 23 and lwIP at 18 — far above any sane render priority —
  and can hold a core for milliseconds during association or DHCP. On a notifier that is
  maximally perverse: frames would drop exactly when a notification arrives, which is the one
  moment the animation has to look good.
- **Hot blit path in `IRAM_ATTR`**, DMA buffers in internal SRAM. Any flash write disables the
  cache on both cores and would otherwise stall the render loop.
- No LVGL tick to manage. `esp_timer_get_time()` drives the keyframe timeline directly.

**Tearing.** The panel exposes no TE pin — confirmed from the schematic — so drawing cannot be
synced to the scan. This turns out not to matter: dirty-span pushes are 1–4 ms, so the tear
window is small, and chunky quantised motion hides tearing far better than smooth motion
would. The pixel-art direction helped here.

### Sprite frames only where geometry runs out

Chevron `><` eyes, the sleeping closed-eye curve, Z's and the sparkle are not rectangles.
Those get small hand-drawn PNG frames converted by `tools/sprite_gen.py` into 1-bit masks —
1-bit, not RGB565, because there are only ever two colours. A 60 x 60 mask is 450 bytes.

Hybrid, deliberately: parametric for anything that interpolates (blinks, droop, drift,
bounce), sprites for fixed shapes. Pure sprites would make smooth blinking need dozens of
frames; pure geometry could not draw a chevron.

### LVGL — dropped

Decision taken, and the numbers back it. Waveshare's own LVGL config on this board allocates
two draw buffers of 33,600 bytes each plus a 48 kB heap — about 115 kB of RAM — against
roughly 11 kB for the renderer above. Flash is 100–150 kB against single-digit kB. And the
obvious mapping of a cell grid onto `lv_obj`s would be ~120 kB in objects alone, with a tree
walk and per-object style and mask work every refresh, to do what is fundamentally a
`memset`.

The subtler argument is the decisive one: **LVGL's animation model is the wrong one here.**
`lv_anim` provides easing curves over continuous values, but a quantised grid throws away
sub-pixel precision. Pixel art wants a keyframe timeline — a list of `{shape, hold_ms}` —
which LVGL does not provide. We would be fighting it, then writing the ~50-line keyframe
player anyway.

The one genuine loss is `lv_indev`'s input plumbing, and it is small: the CST816 does gesture
detection in hardware and raises an interrupt.

Rendering goes directly on esp_lcd, with CST816 touch read directly. Revisit only if
something later needs real text on screen — and if it does, LVGL 8.4 rather than 9.x, which
benchmarks slower on the ESP32-S3.

### Layout

```
ui/face/
  eye.cpp        one eye: height, width, offsets, quantise + draw
  masks.cpp      1-bit sprite blitter for chevrons, Z's, sparkle
  moods.cpp      per-mood animation programs built from the above
  frames.h       generated by tools/sprite_gen.py — do not hand-edit
  tuning.h       every timing constant and the palette, in one place
```

`tuning.h` matters more than it looks. Getting a face to feel alive is iterative — blink
duration, the pause before a saccade, the overshoot on the bounce. Those need to be one
edit and a reflash away, not buried across five files.

### Palette calibration

The on-screen orange and the filament orange will not match by hex — one is backlit and
emissive, the other diffuse and lit by the room. Matching them numerically is the wrong
approach.

So: ship a **calibration mode** (long-press on boot, say) that cycles a handful of candidate
oranges live while the board sits in the printed shell. Pick by eye, save to NVS. Ten
minutes of work that saves an argument with a colour picker.

### Mood → face, restated for real geometry

| Mood | Eyes |
|---|---|
| `SLEEPING` | closed — a short flat bar each, slow vertical breathing drift, occasional Z sprite |
| `WAKING` | bars grow from flat to full height, slight overshoot |
| `CHILL` | full-height bars, random blinks every 2–6 s, occasional lateral drift of both bars together |
| `BORED` | bars at ~60% height, shifted down and both to one side, long slow blinks, periodic droop-and-recover |
| `WORKING` | full height, bars sweep left–right in a repeating scan, faster blink rate |
| `EXCITED` | snap to the `><` chevron sprite, vertical bounce with overshoot, sparkle, bell strike |
| `CONFUSED` | one bar short and one full, small tilt, slow side-to-side shake |

### Accessories — later, optional

The printed variants suggest a cheap trick: sunglasses dropping down over the eyes as a
transient reaction. Pure sprite work, zero architectural cost, easy to add once the base
face is alive. Not v1.

## Architecture

```
Computer (macOS now, Windows later)          ESP32-S3-Touch-LCD-1.69
┌────────────────────────────────┐          ┌─────────────────────────────┐
│ Claude Code hooks              │  HTTP    │ web server :80              │
│  → curl, exec form, async      │ ───────► │  POST /e/{type}             │
│    no shell, no script         │  LAN     │  GET  /health               │
└────────────────────────────────┘          │         │                   │
                                            │         ▼                   │
                                            │  mood engine + energy       │
                                            │         │                   │
                                            │         ▼                   │
                                            │  pixel-grid face renderer   │
                                            └─────────────────────────────┘
```

The board is the stateful half. The host is a dumb event emitter — which is exactly what
makes the Windows port cheap.

### Board API

| Route | Effect |
|---|---|
| `POST /e/{type}` | feeds the mood engine; bumps energy |
| `GET /health` | `{"uptime":…,"rssi":…,"mood":"…","energy":…}` |

Event types are raw facts, not moods: `prompt_submitted`, `turn_finished`, `needs_input`,
`idle`, `error`, `session_started`, `session_ended`. Unknown types get a 404 rather than
being silently swallowed, so a typo in the hook config is visible.

Shared bearer token as a static `-H` argument on `POST`; the board should not take orders
from anything on the LAN that finds port 80. Discovery: see the host section.

## Cross-platform host — settled, and simpler than expected

Requirement: one setup that works on macOS and Windows. Mac first, Windows not a later
bolt-on.

### No script, no binary, no shell

Claude Code hook commands have two execution forms, selected by whether an `args` array is
present:

- **Shell form** (`command` string only) goes through a shell — `sh -c` on macOS, Git Bash
  on Windows if installed, **PowerShell if not**. PowerShell aliases `curl` to
  `Invoke-WebRequest`, which takes completely different flags. A hook written as plain
  `curl -X POST -d '...'` is a coin flip on a Windows box.
- **Exec form** (`command` + `args`) spawns the executable directly. No shell on any
  platform. No tokenization, no quoting rules, no alias.

Exec form is therefore byte-for-byte identical across macOS and Windows, and `curl` is
guaranteed present on both: macOS ships `/usr/bin/curl`, and Windows has shipped
`curl.exe` since 1803 while Claude Code requires 1809 or newer.

The other half of the trick is that **our host never needs to send dynamic data.** The
board owns the mood engine, so a hook only has to report *which* event happened — and that
is known at config time, one hook registration per event. No stdin parsing, no JSON
assembly, so no interpreter and no shipped binary.

The event therefore rides in the URL path rather than a body, which removes the last place
quoting could matter:

```
POST http://<board>/e/prompt_submitted
POST http://<board>/e/turn_finished
POST http://<board>/e/needs_input
POST http://<board>/e/error
```

A compiled Go/Rust helper stays the upgrade path if we later want session names or message
text on screen. Given the face has no text on it, that may never happen.

### Hook mapping

| Claude Code hook | matcher | Board event |
|---|---|---|
| `UserPromptSubmit` | — | `prompt_submitted` |
| `Stop` | — | `turn_finished` |
| `Notification` | `permission_prompt` | `needs_input` |
| `Notification` | `idle_prompt` | `idle` |
| `PostToolUseFailure` | `*` | `error` |
| `StopFailure` | — | `error` |
| `SessionStart` | — | `session_started` |
| `SessionEnd` | — | `session_ended` |

`WORKING` is the span between `prompt_submitted` and `turn_finished` — inferred board-side,
with a safety timeout so a session that dies mid-turn does not leave the face working
forever.

Deliberately **not** hooking `PreToolUse` / `PostToolUse`. They would give a nice
fine-grained energy signal, but they fire on every single tool call and each one spawns a
process. Energy comes from prompt and turn rate instead. If the face ends up feeling flat
during long turns, adding `PostToolUse` alone is a one-line change. ❓

`BORED` and `ASLEEP` are confirmed impossible to source from hooks — `idle_prompt` fires
once, ~60 s after a stop, and never repeats, and nothing fires at all when Claude Code is
not running. Board-side decay timers, as designed. From the board's side, "idle" and "not
running" are the same thing: silence.

### Never stall the human

Hook handlers **block Claude Code's agentic loop by default**, with a 600 s default timeout.
An unreachable board on a blocking hook could hang a session for ten minutes.

Two independent guards, both required:

- `"async": true` on every hook entry — documented fire-and-forget, output and exit code
  ignored.
- `curl -m 2` — bounds the network call itself so dead-board processes do not pile up.

`type: "http"` hooks, where Claude Code does the POST itself with no command at all, look
tempting and are **disqualified**: they have no `async` field, so a dead board can stall
the loop. A peripheral that is often switched off must never be on a blocking path.

### Finding the board

mDNS `.local` works natively on macOS. On Windows it is **not** reliable — Windows 10/11
have partial mDNS wired into modern device-discovery APIs, but not into the Win32 resolver
that `curl` and `ping` use, so `board.local` typically fails without Apple's Bonjour
installed.

So: the board advertises mDNS for the Mac path, but the documented setup is a **DHCP
reservation and a literal IP in the hook config**. It is one line the user edits once, and
it works identically on both platforms.

### Where the config lives

`~/.claude/settings.json`, user scope — this is a personal desk peripheral, not something
to commit into every project. That file is **outside this project directory**; nothing
writes to it without explicit go-ahead. Deliverable is a generated snippet in `tools/` plus
paste instructions.

## Firmware layout

```
platformio.ini
src/
  main.cpp            boot, task wiring
  board/pins.h        pin map from docs/HARDWARE.md
  board/display.cpp   ST7789V2 init, 20-row offset, cell blit
  board/touch.cpp     CST816 over I2C, raw tap coordinates
  board/backlight.cpp LEDC PWM, dim when chill, full when excited
  board/bell.cpp      external striker on LEDC; holds onboard piezo low
  net/wifi.cpp        STA from secrets.h, reconnect, mDNS
  net/httpd.cpp       the two routes, JSON parse, token check
  app/mood.cpp        state machine, energy decay, timers
  ui/face/…           as above
include/secrets.h     gitignored; SSID, password, bearer token
```

## Power — settled

Always USB. No Li-Po, no sleep modes, no battery gauge, no `SYS_EN` latch. Backlight PWM
is for expression (dim while dozing, full when excited), not for saving power. Battery ADC
on GPIO1 goes unused.

## Audible alert — mechanical bell

Not the onboard piezo. An external mechanical striker driven from a GPIO through LEDC PWM.
Still to be worked out with the user: actuator type, drive current, whether a MOSFET stage
and flyback diode are needed, which free GPIO it lands on, and what PWM frequency and duty
actually move it rather than just heating the coil.

Independent of that: the **onboard passive buzzer pin gets driven low at boot** even though
we never use it. Unused and floating is exactly the case that loads the LDO and cooks the
board.

## Build

PlatformIO + Arduino (Arduino-ESP32 3.x), `esp32-s3-devkitc-1` with 16 MB flash and octal
PSRAM set explicitly. No LVGL. Display driven through the IDF `esp_lcd` component, which
Arduino-ESP32 3.x compiles in. SPI at 80 MHz, with 40 MHz as the documented fallback.

**Zero external libraries so far.** The path-based event API carries no body, so there is no
JSON to parse; the handlers are three lines each, so the Arduino core's synchronous
`WebServer` does the job and `ESPAsyncWebServer` is not needed; and the CST816 driver is
written directly against `Wire`. `lewisxhe/SensorLib@0.2.1` only if the IMU or RTC get used.

A blocking HTTP handler is safe here specifically because rendering lives in its own
higher-priority task on the other core. Verified empirically: with a Wi-Fi association
retry storm running on core 0, the render task held 62 fps at 46 µs/frame.

PlatformIO Core 6.1.19 is installed at `~/.platformio/penv/bin/pio` — not on `PATH`, call
it by full path. The `espressif32` platform and xtensa-esp32s3 toolchain were already
cached.

## Open questions

1. **Screen cutout geometry.** The single biggest unknown left. Eye size, spacing and
   vertical placement are all relative to how much of the 240 x 280 panel the shell
   actually exposes, and whether the visible area is square or a portrait slot. Everything
   in `tuning.h` is guesswork until this is measured.
2. **Bored / sleep thresholds** — 5 min and 30 min are placeholders.
5. **Tap-to-ack semantics** — see Touch above.
6. **Board revision** — unknown; changes RTC_INT / SYS_EN / SYS_OUT / onboard buzzer pins.
   Needs a look at the silkscreen.
7. **Bell hardware** — deferred by agreement. Blocks `board/bell.cpp` only.
8. **RTC** — the PCF85063 is there. Any use, or ignore it? A clock does not obviously fit
   a face.
9. **Energy resolution** — prompt/turn rate only, or also hook `PostToolUse` for a
   finer-grained signal at the cost of a process per tool call. Start without; revisit if
   the face reads flat during long turns.

## Verified externally

- The whole host-side design (exec form, `async`, hook names and matchers, the
  `BORED`/`ASLEEP` gap, Windows mDNS) comes from the Claude Code hooks and settings docs
  as of August 2026. Worth a re-read before implementing, since hooks are an actively
  moving part of the product.
- Not yet verified empirically: PowerShell's `curl` alias behaviour under a shell-form
  hook. We avoid the situation entirely by using exec form, so this stays academic unless
  someone hand-writes a shell-form hook.

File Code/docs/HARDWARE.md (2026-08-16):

# Waveshare ESP32-S3-Touch-LCD-1.69 — hardware reference

Product page: <https://www.waveshare.com/esp32-s3-touch-lcd-1.69.htm>
Wiki: <https://www.waveshare.com/wiki/ESP32-S3-Touch-LCD-1.69>
Official examples: <https://github.com/waveshareteam/ESP32-S3-Touch-LCD-1.69>
Schematic (PDF): <https://files.waveshare.com/wiki/ESP32-S3-Touch-LCD-1.69/ESP32-S3-Touch-LCD-1.69-Sch.pdf>

## Core

| Item | Value |
|---|---|
| MCU | ESP32-S3R8, Xtensa LX7 dual-core, up to 240 MHz |
| SRAM / ROM | 512 KB / 384 KB |
| PSRAM | 8 MB (octal, on-package) |
| Flash | 16 MB external |
| Radio | Wi-Fi 2.4 GHz 802.11 b/g/n, Bluetooth 5 (BLE); onboard patch antenna |
| USB | Type-C wired to the ESP32-S3 native USB (USB-CDC for flashing + logs) |

## Peripherals

| Block | Part | Bus |
|---|---|---|
| Display | ST7789V2, 1.69", 240 (H) x 280 (V), 262K colour, RGB565 in the stock demos | 4-wire SPI |
| Touch | CST816D/T capacitive, 7-bit I2C address `0x15` (write `0x2A`, read `0x2B`), 10 kHz–400 kHz | I2C |
| IMU | QMI8658C, 3-axis accel + 3-axis gyro | I2C |
| RTC | PCF85063 + SH1.0 backup-battery header | I2C |
| Charger | ETA6098 Li-ion charger, MX1.25 battery connector | — |
| Audio | passive buzzer | GPIO/PWM |
| Buttons | BOOT, RST, and a multi-function PWR button (single / double / long press) | — |

The ST7789V2 controller has 240 x 320 of RAM but the panel is 240 x 280, so the
display window needs the usual 20-pixel row offset. Corners are rounded — keep
anything important away from them.

## Pin map

Cross-checked two ways: `examples/arduino/libraries/Mylibrary/pin_config.h` in the official
repo, and the net labels extracted from the schematic PDF. They agree.

| Signal | GPIO | Confirmed by |
|---|---|---|
| LCD_DC | 4 | both |
| LCD_CS | 5 | both |
| LCD_SCK / LCD_SCL | 6 | both |
| LCD_MOSI / LCD_SDA | 7 | both |
| LCD_RST | 8 | both |
| LCD_BL (backlight) | 15 | both |
| I2C SCL | 10 | both |
| I2C SDA | 11 | both |
| TP_RST | 13 | both |
| TP_INT | 14 | both |
| Battery voltage ADC | 1 | wiki only |

**One shared I2C bus, confirmed.** The schematic ties `TP_SCL` and `RTC_SCL` both to GPIO10,
and `TP_SDA` / `RTC_SDA` both to GPIO11. Touch, RTC, and IMU are all on it.

**No TE pin.** The LCD FPC connector carries only `LCD_DC`, `LCD_CS`, `LCD_SCL`, `LCD_SDA`,
`LCD_RST`, `LEDK`, the supplies and the touch signals. There is no tearing-effect output, so
frame-synced drawing is not possible — see Rendering constraints below.

**An SHTC3 temperature/humidity part appears in the schematic** on the same I2C bus. Likely
unpopulated on this SKU (the schematic is shared across board variants). An I2C scan will
settle it.

### Pins that moved between board revisions — and why

The wiki publishes an old-vs-new table:

| Signal | Old revision | New revision |
|---|---|---|
| Buzzer | GPIO33 | GPIO42 |
| RTC_INT | GPIO41 | GPIO39 |
| SYS_EN (power latch) | GPIO35 | GPIO41 |
| SYS_OUT (PWR button sense) | GPIO36 | GPIO40 |

**The published schematic is the old revision** — its net labels read `GPIO35 → SYS_EN` and
`GPIO36 → SYS_OUT`.

The reason for the change looks clear, and it matters. **GPIO33–37 are consumed by the
in-package octal PSRAM on the ESP32-S3R8** (SPIIO4–7 and SPIDQS). The old revision put the
buzzer on 33, SYS_EN on 35, and SYS_OUT on 36 — all inside that reserved range, so on an
8 MB-PSRAM part they cannot work as general IO. The new revision moves all of them to
39–42, which are clear.

Practical consequence: **do not design anything onto GPIO 33–37.** If this unit turns out to
be an old revision, its buzzer and power-button pins are unusable rather than merely
different, and the PWR button is off the table.

### Free GPIOs for the mechanical bell

Taken: 4, 5, 6, 7, 8, 15 (LCD), 10, 11, 13, 14 (I2C + touch), 1 (battery ADC),
19/20 (USB), 33–37 (octal PSRAM), 39–42 (buzzer / RTC_INT / SYS_EN / SYS_OUT on the new
revision), plus the flash SPI pins and GPIO0 (BOOT).

Reasonable candidates, avoiding strapping pins (0, 3, 45, 46) and the UART0 pair (43, 44):
**17, 18, 21, 38, 47, 48**. Needs a multimeter check against the actual board before
committing.

## Rendering constraints

Established from the ST7789 datasheet, ESP-IDF documentation, and the Waveshare examples.

| Item | Value |
|---|---|
| ST7789 serial write cycle, `TSCYCW` | 16 ns min → **62.5 MHz** spec ceiling for writes |
| ST7789 serial read cycle, `TSCYCR` | 150 ns min → 6.67 MHz for reads |
| ESP32-S3 SPI clocks actually selectable | 80, 40, 26.67, 20 MHz — integer divisors of 80 MHz, nothing between |
| Waveshare's own examples | pin 40 MHz in both the Arduino and IDF versions |
| Full frame, 240 x 280 RGB565 | 134,400 bytes → 13.4 ms at 80 MHz, 26.9 ms at 40 MHz |
| SPI transaction overhead | 9 µs polling/CPU, 11 µs polling/DMA, 26 µs interrupt/DMA |
| Per-rect command cost | CASET + RASET + RAMWR emitted on every `draw_bitmap`, ~35–50 µs |

80 MHz is a 28% overclock past the datasheet, but it is what the field runs, including a
report covering this exact 240x280 panel. Waveshare's 40 MHz is the conservative choice.
Start at 80, validate at temperature inside the printed shell, fall back to 40 if artifacts
appear — there is no step in between.

### Traps

- **`INVON` is mandatory.** The IDF example calls `esp_lcd_panel_invert_color(panel, true)`.
  Skip it on a hand-rolled init and the orange field comes up cyan.
- **The 20-row offset has two pairs.** Waveshare's Arduino call is
  `Arduino_ST7789(bus, LCD_RST, 0, true, 240, 280, 0, 20, 0, 20)`. The second pair applies
  under rotation 2/3; set only the first and the image shifts when rotated. In esp_lcd it is
  one call: `esp_lcd_panel_set_gap(panel, 0, 20)`.
- **RGB565 byte order.** ST7789 wants big-endian, the ESP32 is little-endian. With only two
  colours on screen, byte-swap the palette once at startup and every fill is correct for
  free.
- **`Arduino_ESP32SPI` does not use DMA.** It pokes the SPI FIFO directly and busy-waits in
  a spin loop, 32 pixels at a time — 2,100 chunked transfers and 100% CPU for a full frame.
  `Arduino_ESP32SPIDMA` is the real DMA backend in the same library.
- **LEDC channels can share a timer and corrupt each other's frequency.** With both the
  backlight and the bell on PWM, give each its own LEDC timer via `ledcAttachChannel`.
- **GPIO 6/7 are not the SPI2 IO_MUX pins** (those are 10–13), so the LCD routes through the
  GPIO matrix. The documented 26/40 MHz GPIO-matrix ceilings are input/MISO setup limits and
  the panel is write-only, so 80 MHz output should be fine — but this is the single claim
  most worth validating on hardware early.
- **Two bugs in Waveshare's examples not to copy:** a stray `esp_timer` in the Arduino demo
  that calls `esp_restart()` after 30 ticks, and `CONFIG_ESPTOOLPY_FLASHSIZE_4MB=y` in the
  IDF `sdkconfig.defaults` on a 16 MB board.

### Power-button latch

Pressing PWR connects battery power and boots the board. Firmware must then drive
`SYS_EN` high to hold the latch closed; releasing PWR does not cut power. After boot,
PWR pulls `SYS_OUT` low, so firmware reads `SYS_OUT` to detect single / double / long
press. Driving `SYS_EN` low disconnects battery power — that is the software power-off.

### Buzzer warning

Waveshare's FAQ: drive the buzzer pin low early in boot. The passive buzzer behaves like
a resistor and draws current continuously if the pin floats or idles high, which loads
the LDO and makes the board run hot.

## Toolchains on this machine (checked 2026-08-15)

| Tool | State |
|---|---|
| PlatformIO Core | 6.1.19 at `~/.platformio/penv/bin/pio` — not on `PATH` |
| `espressif32` platform | 7.0.1 (Arduino-ESP32 2.0.17 / IDF 4.4.7) |
| Arduino IDE.app | installed |
| ESP-IDF (`idf.py`) | not installed |
| `arduino-cli` | not installed |
| Node / npm | not installed |
| Python | **3.9.6 system only.** No Homebrew, pyenv, uv or conda |
| Board | attached via a Dell dock: `/dev/cu.usbmodem202201`, Espressif USB JTAG/serial unit, VID `0x303A` PID `0x1001` |

### Why we are on Arduino-ESP32 2.0.17 rather than 3.x

Arduino-ESP32 3.x on PlatformIO means the pioarduino fork, which **hard-requires Python
3.10+**. This machine has only system Python 3.9.6 and no package manager to get a newer
one, so the platform installs and then refuses to build.

The cost is small: esp_lcd exists in IDF 4.4 with the same ST7789 driver, `set_gap`, and
`invert_color`. Two API names differ and are handled behind `ESP_IDF_VERSION` checks in
`src/main.cpp` — `color_space` vs `rgb_ele_order`, and `esp_lcd_panel_disp_off()` vs
`esp_lcd_panel_disp_on_off()`.

To move to 3.x later: install Python 3.10+, rebuild the PlatformIO venv, and swap the
`platform` line in `platformio.ini` (the pioarduino URL is in a comment there).

## Library versions Waveshare pins for the Arduino examples

| Library | Version | Notes |
|---|---|---|
| GFX_Library_for_Arduino | 1.4.9 | ST7789 driver |
| lvgl | 8.4.0 | offline install recommended |
| SensorLib | 0.2.1 | PCF85063 + QMI8658 |
| Arduino_DriveBus | — | CST816 touch, offline install only |
| Mylibrary | — | the `pin_config.h` above, offline install only |
| esp32 board package | >= 3.0.5 | — |

## Measured on this unit (2026-08-15, bring-up firmware)

| Item | Result |
|---|---|
| Chip | ESP32-S3 QFN56, revision v0.2, MAC `a0:f2:62:e4:c5:14` |
| PSRAM | embedded 8 MB (AP_3v3) — octal, so GPIO 33–37 are confirmed reserved |
| Flash | 16 MB, quad, 3.3 V, manufacturer `0x20` device `0x4018` |
| USB | USB-Serial/JTAG, no UART bridge |
| I2C devices on GPIO 10/11 | `0x15` CST816 touch, `0x51` PCF85063 RTC, `0x6B` QMI8658C IMU, `0x7E` unidentified |
| Board revision | **new** — confirmed by the piezo responding on GPIO42 |
| Onboard piezo | audible on GPIO42 via LEDC; two-chirp celebration confirmed by ear |
| SHTC3 | **absent** — nothing at `0x70`, so that footprint is unpopulated on this SKU |
| Full-screen fill, 240x280 | **18.65 ms** |
| Blink frame, both eyes, dirty spans only | **579 µs** |

**80 MHz SPI is confirmed working.** The full-screen fill measures 18.65 ms. Wire time at
80 MHz is 13.4 ms, and the fill runs as 56 chunked transactions, so ~5 ms of command
overhead is expected. At 40 MHz the wire time alone would be 26.9 ms — well above what was
measured — so the clock took.

**Render headroom is enormous.** A blink costs 579 µs against a 16 ms frame budget: under
4%. The dirty-span approach is doing what it was supposed to, and the remaining budget can
go entirely on animation richness.

`0x7E` sits in the 0x78–0x7F range that I2C reserves for 10-bit addressing, which most
scanners skip. Most likely a scan artifact rather than a real device — worth revisiting
only if something on the bus misbehaves.

## Unverified

- I2C addresses for the QMI8658C and PCF85063. An I2C scan on GPIO 10/11 settles this and
  the SHTC3 question in one go.
- ~~Which board revision this unit is.~~ **Resolved: new revision.** Driving GPIO42 with
  LEDC produces audible sound from the onboard piezo, which only holds on the new pin map.
  So RTC_INT is 39, SYS_EN 41, SYS_OUT 40, buzzer 42, and GPIO 33-37 stay off-limits to the
  octal PSRAM.
- Whether 80 MHz SPI is stable on this unit at temperature inside a printed shell.

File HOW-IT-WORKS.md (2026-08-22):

# How it works

The short version: **Claude Code runs `curl`.** That's the whole integration.

No daemon, no library, no cloud service, no API key on the device, and for
almost everything, no script either.

---

## The one line that does most of the work

Claude Code has a feature called **hooks**: entries in its settings file that run
a command when something happens. The command here is literally `curl`:

```json
{
  "type": "command",
  "command": "curl",
  "args": [
    "-s", "-m", "2", "-X", "POST",
    "-H", "Authorization: Bearer <token>",
    "http://192.168.1.26/e/turn_finished"
  ],
  "async": true
}
```

That is the entire mechanism. Claude finishes a turn, Claude Code fires that
`curl`, the board gets a POST, the face grins.

There are twelve of these, one per thing worth knowing about. They differ only
in the last word of the URL. The whole block, as it actually sits in
`~/.claude/settings.json`, is in
[`Code/docs/settings.example.json`](Code/docs/settings.example.json).

## Why there is no JSON, and why that matters

The event name is in the **URL path**, not in a request body.

That sounds like a detail; it is the reason no script is needed. With no body,
there is nothing to build, nothing to quote, and nothing to escape — so the
command is a fixed list of arguments that never changes. `curl` ships with
macOS, with Windows, and with essentially every Linux, and the same config works
byte-for-byte on all three.

Two smaller decisions carry real weight:

**`args` as a list, not a string.** Claude Code spawns `curl` directly instead of
handing a string to a shell. No quoting rules, no PATH surprises, and no
difference between platforms. (A string would go through `sh` on macOS but
PowerShell on Windows, where `curl` is an alias for something else entirely.)

**`async: true`.** The board is a desk ornament. It must never be able to slow
down the editor. Hooks normally block Claude Code until they finish; this one is
fire-and-forget, and `-m 2` caps the request at two seconds. Unplug the board
mid-session and nothing notices.

## What the computer sends, and what the board decides

The computer reports **facts**. It never says how to feel about them.

| Claude Code does this | The board is told |
|---|---|
| you submit a prompt | `prompt_submitted` |
| a turn finishes | `turn_finished` |
| a permission prompt appears | `needs_input` |
| Claude asks you a question | `needs_input` |
| you answer it | `answered` |
| a tool call fails | `error` |
| the usage limit is hit | `limit_reached` |
| a session starts or ends | `session_started` / `session_ended` |

Everything expressive happens **on the board**: which mood those facts add up
to, how the eyes move, when to go red, when to ring.

That split is not tidiness, it is necessary. Two of the moods — **bored** and
**asleep** — are the *absence* of events. No hook can fire to say "nothing has
happened for five minutes". Only something keeping its own clock can know that,
so the board keeps the clock. A useful side effect: the face keeps behaving
correctly when the computer sleeps, the Wi-Fi drops, or Claude Code is closed.

## The one exception: the usage dials

The two ring gauges — five-hour and weekly — are the only part that needs a
script, for one reason: **no hook carries your rate limits.**

They exist in exactly one place, the JSON Claude Code feeds to its **status
line**. So a small script sits there, reads two numbers out, and forwards them
to the board with the same `curl` as everything else. It prints an ordinary
status line at the same time, so it earns its keep either way.

Everything else — moods, faces, colours, sounds, the bell — works with the
script absent.

## What the board never does

- **It never talks to Anthropic.** No API key, no account, no token beyond the
  shared word it checks on incoming requests.
- **It never leaves your network.** The only outbound traffic is an NTP time
  sync at boot, so it can say "resets at 15:33" instead of counting down.
- **It has no app.** The settings page is served by the board itself. You open
  its IP in a browser and you are talking to the ESP32, not to a service.

If your internet goes down, the mascot carries on.

## The whole picture

```
   your computer                            the board
   ─────────────                            ─────────
   Claude Code
     │
     ├─ hook fires ──► curl ──► HTTP POST ──► /e/needs_input
     │                          (your LAN)         │
     │                                             ▼
     │                                      mood engine + clock
     │                                             │
     └─ status line ─► script ─► POST ────► /limits    │
        (usage % only)                              ▼
                                          face · dials · bell
                                                    │
                                       browser ◄─── settings page
```

Twelve `curl` invocations and one small script. That is the entire protocol.

## Why it was built this way

The goal was that someone could build this without becoming its maintainer.
Flash the board once, open its web page, and never touch the firmware again —
Wi-Fi credentials included. Forty-six settings live on that page, from the
buzzer's pitch to the eye spacing, and there is a pixel editor for drawing your
own faces.

Keeping the wire protocol down to "run `curl`" is what makes the rest of that
possible. There is no version to keep in step, no dependency to break, and
nothing to reinstall when Claude Code updates.

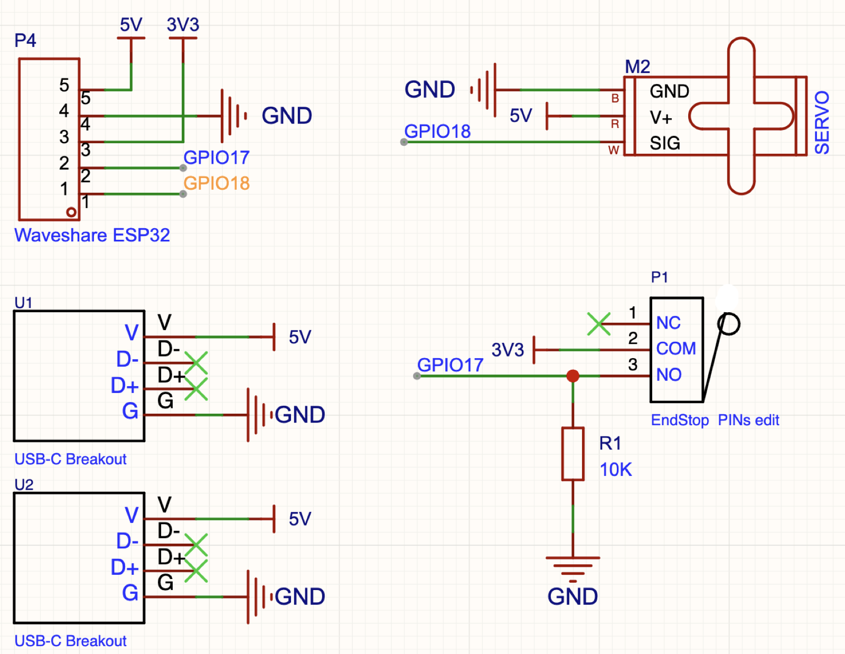
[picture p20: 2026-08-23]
Hardware/Schematics.png

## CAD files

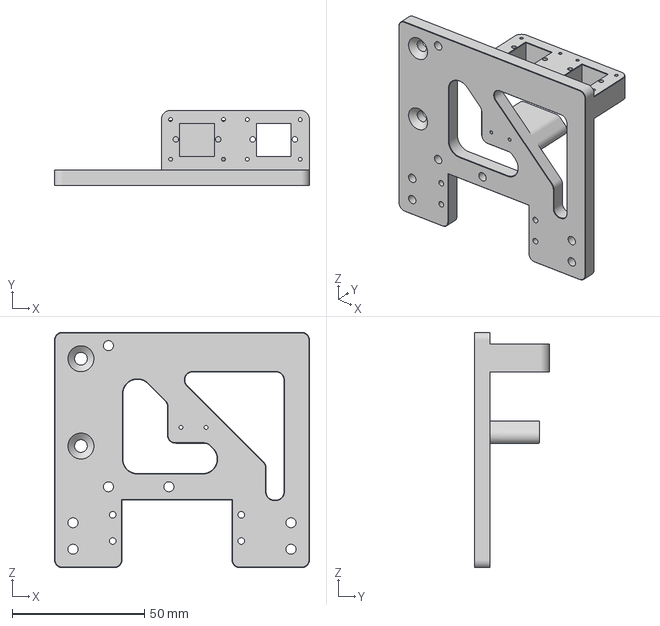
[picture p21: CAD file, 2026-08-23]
CAD/3MF/Bell Plate V1 (1).3mf
96.4 x 28.5 x 89.0 mm

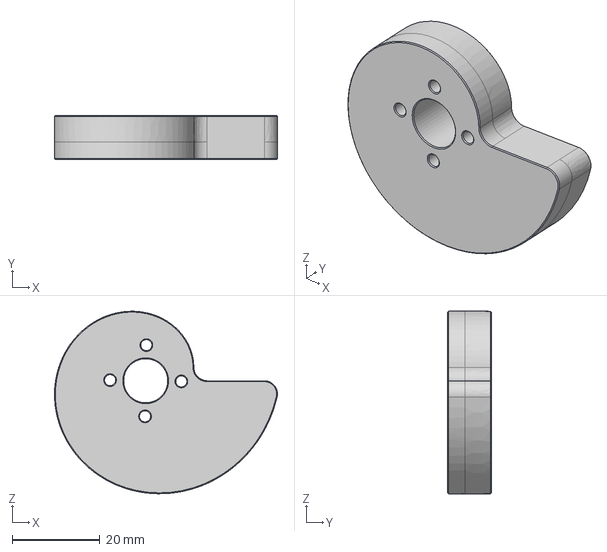
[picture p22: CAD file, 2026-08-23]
CAD/STEP/Bell Cam 2.step
50.7 x 10.0 x 41.5 mm

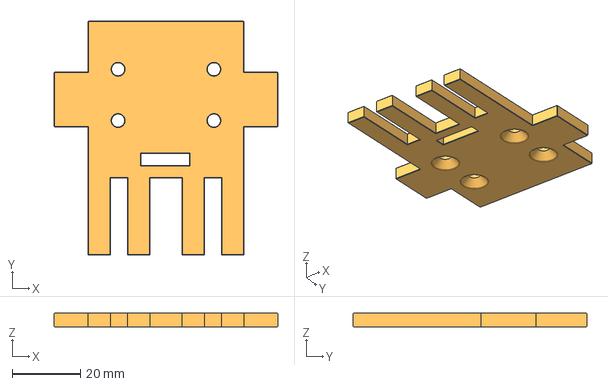
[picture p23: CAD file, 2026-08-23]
CAD/3MF/Claude Back Shell.3mf
65.5 x 68.5 x 4.00 mm

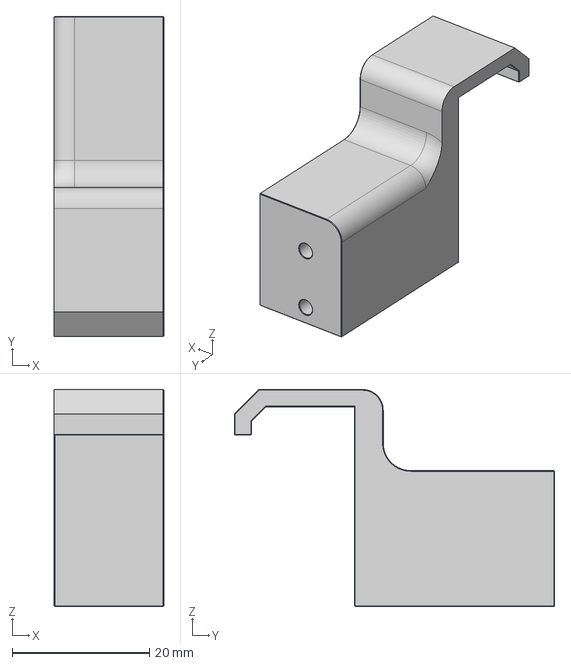
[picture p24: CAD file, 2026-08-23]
CAD/STEP/Monitor Hook.step
16.0 x 46.7 x 31.6 mm

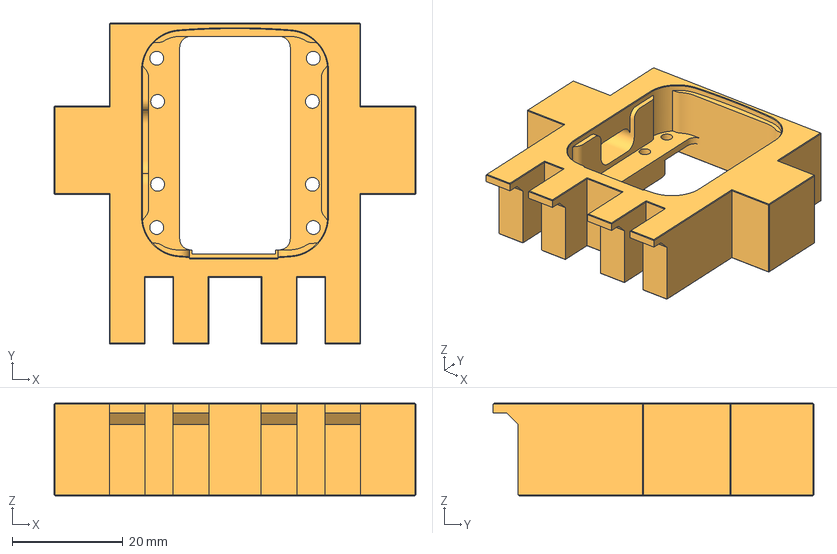
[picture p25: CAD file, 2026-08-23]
CAD/3MF/Claude Front Shell.3mf
65.5 x 58.0 x 16.8 mm

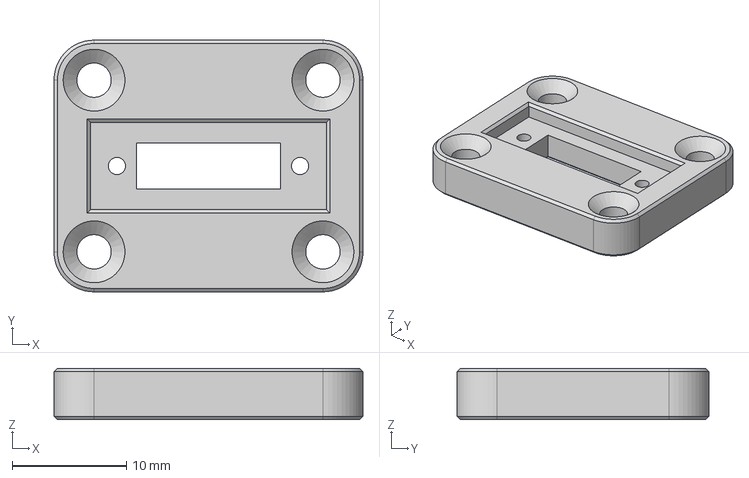
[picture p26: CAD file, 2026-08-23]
CAD/STEP/USB C Plate V2.step
27.0 x 22.0 x 4.50 mm

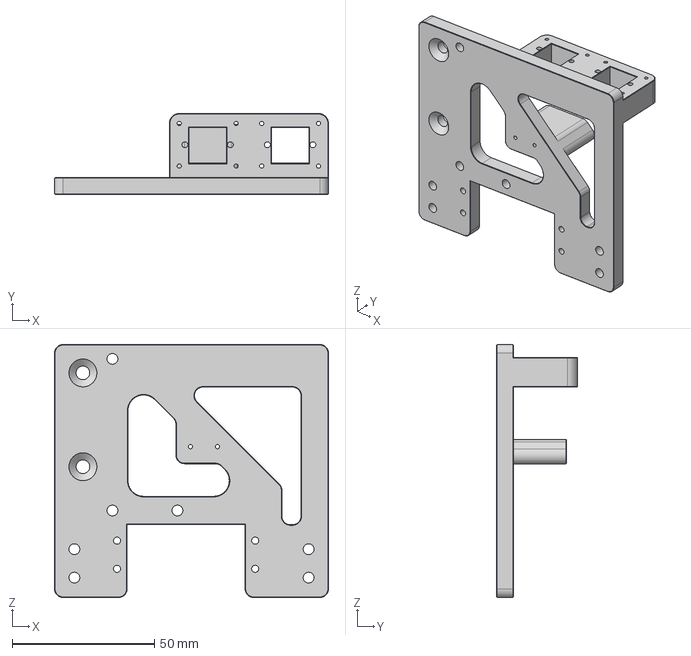
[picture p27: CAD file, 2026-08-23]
CAD/STEP/Bell Plate V2.step
96.4 x 28.5 x 89.0 mm

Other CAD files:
CAD/STEP/Monitor Test Hook Mirrored.step
CAD/3MF/Bell Cam 2.3mf
CAD/3MF/Monitor Hook.3mf
CAD/3MF/Monitor Test Hook Mirrored.3mf
CAD/3MF/USB C Plate V2.3mf

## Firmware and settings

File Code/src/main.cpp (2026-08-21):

// Claude Monitor Companion — mascot face.
//
// A Waveshare ESP32-S3-Touch-LCD-1.69 sitting in a 3D-printed shell shaped like
// the Claude mascot. The screen is its face: an orange field with two black
// bars for eyes, whose mood mirrors what Claude Code is doing on the computer.
//
// Claude Code hooks POST bare event names at the board over the LAN; the mood
// engine here decides what the face does about them. Serial commands drive the
// same events by hand, and force individual moods, so the animation can be
// tuned without the host in the loop. See README.md.

#include <Arduino.h>
#include <Wire.h>

#include "bell.h"
#include "config.h"
#include "customface.h"
#include "display.h"
#include "face.h"
#include "mood.h"
#include "net.h"
#include "pins.h"
#include "touch.h"
#include "usage.h"
#include "tuning.h"
#include "views.h"

namespace {

TaskHandle_t s_render_task = nullptr;
bool s_touch_ok = false;

// Swipe cycles the face style; a tap acknowledges an alert and silences the
// bell, the same thing the host's ack would do.
//
// Both are derived here from the raw coordinate stream rather than from the
// CST816's gesture register. The chip only decides a gesture happened once the
// finger lifts, and it latches the code afterwards, so a second swipe the same
// way reads as unchanged and is dropped — the exact motion someone makes when
// flicking through styles. Watching the coordinates instead means the swipe
// fires the moment it passes the threshold, mid-drag, which also feels quicker.
struct Drag {
  bool down;
  bool fired;
  int16_t x0, y0;
  uint32_t t0;
};
Drag s_drag = {};

void service_touch() {
  if (!s_touch_ok) return;

  touch::Event e;
  while (touch::poll(e)) {
    if (e.pressed && !s_drag.down) {
      s_drag.down = true;
      s_drag.fired = false;
      s_drag.x0 = e.x;
      s_drag.y0 = e.y;
      s_drag.t0 = millis();
      continue;
    }

    const int dx = e.x - s_drag.x0;
    const int dy = e.y - s_drag.y0;

    if (e.pressed) {
      if (s_drag.fired) continue;
      const int adx = abs(dx), ady = abs(dy);
      if (max(adx, ady) < SWIPE_MIN_PX) continue;
      // Whichever axis dominates wins. The raw-to-panel orientation is still
      // unconfirmed, so keying off the dominant axis rather than X alone means
      // a horizontal flick works even if the driver's axes turn out swapped.
      // Sideways changes the face, up-down changes the screen. If the touch
      // controller's axes turn out swapped on a given panel, one setting flips
      // the interpretation rather than needing a rebuild.
      bool horizontal = adx >= ady;
      if (config::v::swipe_swap_axes()) horizontal = !horizontal;
      const int travel = horizontal ? dx : dy;
      const int dir = (travel > 0) ? 1 : -1;
      if (horizontal) {
        face::cycle_style(SWIPE_INVERT ? -dir : dir);
      } else {
        views::cycle(dir);
      }
      Serial.printf("swipe dx %d dy %d -> %s\n", dx, dy,
                    horizontal ? "style" : "view");
      s_drag.fired = true;
      continue;
    }

    // Released.
    if (s_drag.down && !s_drag.fired) {
      const uint32_t held = millis() - s_drag.t0;
      if (held <= TAP_MAX_MS && abs(dx) <= TAP_MAX_PX && abs(dy) <= TAP_MAX_PX) {
        Serial.printf("tap %d,%d\n", e.x, e.y);
        face::poke();
        mood::post(mood::Event::Ack);
      }
    }
    s_drag.down = false;
  }
}

void i2c_scan() {
  Serial.println("I2C scan on SDA=11 SCL=10:");
  int found = 0;
  for (uint8_t addr = 1; addr < 127; addr++) {
    Wire.beginTransmission(addr);
    if (Wire.endTransmission() != 0) continue;
    const char *guess = "?";
    switch (addr) {
      case 0x15: guess = "CST816 touch"; break;
      case 0x51: guess = "PCF85063 RTC"; break;
      case 0x6A:
      case 0x6B: guess = "QMI8658C IMU"; break;
      case 0x70: guess = "SHTC3 temp/humidity"; break;
    }
    Serial.printf("  0x%02X  %s\n", addr, guess);
    found++;
  }
  if (found == 0) Serial.println("  nothing found");
}

// Rendering gets its own task on core 1. Wi-Fi and lwIP run at priorities 23
// and 18 on core 0 and can hold a core for milliseconds during association or
// DHCP — sharing a core with them would drop frames exactly when a notification
// arrives, which is the one moment the face has to look good.
void render_task(void *) {
  TickType_t last = xTaskGetTickCount();
  uint32_t frames = 0, busy_us = 0;
  uint32_t report_at = millis() + 10000;

  for (;;) {
    const uint32_t now = millis();
    const uint32_t t0 = micros();

    mood::tick(now);

    // The data screens own the whole panel when they are up. Coming back to the
    // face needs an explicit repaint, since its dirty tracking has no idea
    // something else drew over it.
    static views::View last_view = views::View::Face;
    const bool handled = views::render(now, face::background());
    if (views::current() != last_view) {
      last_view = views::current();
      if (last_view == views::View::Face) face::refresh();
    }
    if (!handled) face::render(mood::current(), mood::energy(), now);

    bell::play(mood::take_cue());

    busy_us += micros() - t0;
    frames++;

    if (now >= report_at) {
      Serial.printf("%-8s energy %3u   %lu fps, %lu us/frame busy\n",
                    mood::name(mood::current()), mood::energy(),
                    (unsigned long)(frames / 10),
                    (unsigned long)(frames ? busy_us / frames : 0));
      frames = 0;
      busy_us = 0;
      report_at = now + 10000;
    }

    vTaskDelayUntil(&last, pdMS_TO_TICKS(FRAME_PERIOD_MS));
  }
}

// Auto-cycle through every mood, for judging the animations without having to
// drive real events at the board.
bool s_demo = false;
uint32_t s_demo_next = 0;
uint8_t s_demo_step = 0;

const mood::Mood kAllMoods[] = {
    mood::Mood::Chill,   mood::Mood::Working,  mood::Mood::Excited,
    mood::Mood::Confused, mood::Mood::Angry,   mood::Mood::Limit,
    mood::Mood::Bored,    mood::Mood::Sleeping, mood::Mood::Waking,
};
const uint8_t kMoodCount = sizeof(kAllMoods) / sizeof(kAllMoods[0]);

void service_demo() {
  if (!s_demo || millis() < s_demo_next) return;
  const mood::Mood m = kAllMoods[s_demo_step % kMoodCount];
  s_demo_step++;
  mood::force(m, /*sticky=*/true);
  Serial.printf("demo -> %s\n", mood::name(m));
  s_demo_next = millis() + 5000;
}

void print_help() {
  Serial.println("events : p prompt | f turn finished | n needs input");
  Serial.println("         e error  | i idle          | s session start");
  Serial.println("         x session end | a ack (touch) | k answered");
  Serial.println("moods  : 1 chill 2 working 3 excited 4 confused 5 angry");
  Serial.println("         6 limit 7 bored 8 sleeping 9 waking | d auto-cycle");
  Serial.println("views  : [ ] style (swipe sideways) | v next screen (swipe up)");
  Serial.println("tuning : c orange | b bell | z buzz | l long | w scan | r reach | h ?\n"
                 "wifi   : W show stored creds (lengths only) | R restore compiled creds");
}

// A line-oriented escape hatch: "set <key> <value>" reaches any setting over
// USB. The web page is the normal way in, but a device sealed in a case that
// cannot join a network cannot be reached that way -- which is exactly when you
// most need to change something.
void handle_line(const String &line) {
  if (!line.startsWith("set ")) {
    Serial.println("usage: set <key> <value>   (try 'get' to list)");
    return;
  }
  const int sp = line.indexOf(' ', 4);
  if (sp < 0) {
    Serial.println("usage: set <key> <value>");
    return;
  }
  const String key = line.substring(4, sp);
  const String val = line.substring(sp + 1);

  const config::Field *f = config::fields();
  for (size_t i = 0; i < config::field_count(); i++) {
    if (key != f[i].key) continue;
    bool ok;
    if (f[i].type == config::Type::Text || f[i].type == config::Type::Password) {
      ok = config::set_str(f[i].key, val.c_str());
    } else {
      ok = config::set(f[i].key, val.toInt());
    }
    Serial.printf("%s %s = %s\n", ok ? "set" : "REJECTED", f[i].key, val.c_str());
    if (ok) {
      face::refresh();
      bell::reconfigure();
    }
    return;
  }
  Serial.printf("no such setting: %s\n", key.c_str());
}

void list_settings() {
  const config::Field *f = config::fields();
  for (size_t i = 0; i < config::field_count(); i++) {
    if (f[i].type == config::Type::Password) {
      Serial.printf("  %-20s (hidden)\n", f[i].key);
    } else if (f[i].type == config::Type::Text) {
      Serial.printf("  %-20s %s\n", f[i].key, config::get_str(f[i].key));
    } else {
      Serial.printf("  %-20s %d\n", f[i].key, (int)config::get(f[i].key));
    }
  }
}

void handle_command(char c) {
  switch (c) {
    case 'p': mood::post(mood::Event::PromptSubmitted); break;
    case 'f': mood::post(mood::Event::TurnFinished);    break;
    case 'n': mood::post(mood::Event::NeedsInput);      break;
    case 'e': mood::post(mood::Event::Error);           break;
    case 'i': mood::post(mood::Event::Idle);            break;
    case 's': mood::post(mood::Event::SessionStarted);  break;
    case 'x': mood::post(mood::Event::SessionEnded);    break;
    case 'a': mood::post(mood::Event::Ack);             break;
    case 'k': mood::post(mood::Event::Answered);        break;
    case '1': case '2': case '3': case '4': case '5': case '6': case '7':
    case '8': case '9': {
      const mood::Mood m = kAllMoods[c - '1'];
      mood::force(m, /*sticky=*/true);
      Serial.printf("forced %s\n", mood::name(m));
      return;
    }
    case 'd':
      s_demo = !s_demo;
      s_demo_next = 0;
      Serial.printf("demo cycle %s\n", s_demo ? "on" : "off");
      return;
    case 'c':
      face::next_orange();
      Serial.printf("orange candidate %u\n", face::orange_index());
      return;
    case '[':
    case ']':
      face::cycle_style(c == ']' ? +1 : -1);
      return;  // the render task logs the result; reading it here would be stale
    // Not printing the name: the change is applied by the render task, so
    // reading it here would report the previous view.
    case 'v': views::cycle(1); Serial.println("next view"); return;
    case 'W': net::wifi_diag(); return;
    case 'R': net::wifi_restore_defaults(); return;
    case 'w': net::scan(); return;
    case 'r': net::probe(); return;
    case 'b': bell::strike(); return;
    case 'z': bell::celebrate(); Serial.println("short buzz"); return;
    case 'l': bell::long_buzz(); Serial.println("long buzz"); return;
    case 'h':
      Serial.printf("%s/%s energy %u  wifi %s %s  heap %lu\n",
                    mood::name(mood::current()), face::style_name(),
                    mood::energy(),
                    net::connected() ? "up" : "down", net::ip(),
                    (unsigned long)ESP.getFreeHeap());
      return;
    case '?': print_help(); return;
    default: return;
  }
  Serial.printf("-> %c\n", c);
}

}  // namespace

void setup() {
  Serial.begin(115200);
  const uint32_t t0 = millis();
  while (!Serial && millis() - t0 < 2000) delay(10);

  Serial.println();
  Serial.println("=== Claude Monitor Companion ===");
  Serial.printf("chip  : %s rev %d @ %lu MHz\n", ESP.getChipModel(),
                ESP.getChipRevision(), (unsigned long)getCpuFrequencyMhz());
  Serial.printf("flash : %lu bytes   PSRAM: %lu bytes\n",
                (unsigned long)ESP.getFlashChipSize(),
                (unsigned long)ESP.getPsramSize());

  if (ESP.getPsramSize() == 0) {
    Serial.println("WARNING: no PSRAM — check memory_type = qio_opi");
  }

  config::begin();

  Wire.begin(PIN_I2C_SDA, PIN_I2C_SCL, 400000);
  i2c_scan();

  if (!display::begin()) {
    Serial.println("FATAL: display init failed");
    while (true) delay(1000);
  }

  customface::begin();
  usage::begin();
  views::begin();
  face::begin();
  mood::begin(millis());
  bell::begin();

  s_touch_ok = touch::begin();
  Serial.printf("touch : %s (chip id 0x%02X)\n",
                s_touch_ok ? "ready" : "NOT RESPONDING", touch::chip_id());

  Serial.printf("face  : style %s, orange %u\n", face::style_name(),
                face::orange_index());

  net::begin();
  print_help();

  xTaskCreatePinnedToCore(render_task, "render", 4096, nullptr, 3,
                          &s_render_task, 1);
}

void loop() {
  // Single keystrokes stay as they were; anything ending in a newline is
  // treated as a line command, so both styles work on the same port.
  static String line;
  while (Serial.available()) {
    const int c = Serial.read();
    if (c == '\n' || c == '\r') {
      line.trim();
      if (line == "get") list_settings();
      else if (line.length() > 1) handle_line(line);
      else if (line.length() == 1) handle_command(line[0]);
      line = "";
    } else if (c >= ' ') {
      line += (char)c;
      if (line.length() > 80) line = "";
    }
  }
  // Touch is serviced here rather than in the render task: the CST816 shares
  // the I2C bus with the RTC and IMU, and I2C stalls must never land inside the
  // frame budget.
  service_touch();
  service_demo();
  bell::tick();
  net::tick();
  usage::tick(net::connected());
  // 5 ms, not 20: this is the swipe sampling rate, and a flick that only gets
  // sampled three times does not read as a flick.
  delay(5);
}

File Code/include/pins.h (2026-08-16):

#pragma once

// Waveshare ESP32-S3-Touch-LCD-1.69 pin map.
// Cross-checked against the vendor's Mylibrary/pin_config.h and the net labels
// in the official schematic PDF. See docs/HARDWARE.md.

// LCD — ST7789V2, 4-wire SPI
#define PIN_LCD_DC    4
#define PIN_LCD_CS    5
#define PIN_LCD_SCK   6
#define PIN_LCD_MOSI  7
#define PIN_LCD_RST   8
#define PIN_LCD_BL    15

// Panel geometry. The controller has 240x320 of RAM behind a 240x280 panel,
// hence the row offset.
#define LCD_W         240
#define LCD_H         280
#define LCD_GAP_X     0
#define LCD_GAP_Y     20

// One shared I2C bus: CST816 touch, QMI8658C IMU, PCF85063 RTC,
// and possibly an SHTC3 (may be unpopulated on this SKU).
#define PIN_I2C_SCL   10
#define PIN_I2C_SDA   11
#define PIN_TP_RST    13
#define PIN_TP_INT    14

// Battery divider. Unused — this build is always USB-powered.
#define PIN_BAT_ADC   1

// Revision-dependent pins. GPIO 33-37 are consumed by the in-package octal
// PSRAM on the ESP32-S3R8, so the old revision's assignments (buzzer 33,
// SYS_EN 35, SYS_OUT 36) are not merely different — they cannot work.
//
// CONFIRMED NEW REVISION: driving GPIO42 with LEDC produces audible sound from
// the onboard piezo on this unit, which is only true of the new map. The
// old-revision branch below is kept for anyone building against a different
// board, but is not the one in use here.
#define BOARD_REV_NEW 1
#if BOARD_REV_NEW
  #define PIN_BUZZER   42
  #define PIN_RTC_INT  39
  #define PIN_SYS_EN   41
  #define PIN_SYS_OUT  40
#else
  #define PIN_BUZZER   33  // unusable with octal PSRAM
  #define PIN_RTC_INT  41
  #define PIN_SYS_EN   35  // unusable with octal PSRAM
  #define PIN_SYS_OUT  36  // unusable with octal PSRAM
#endif

// External mechanical bell striker, on LEDC PWM. Set to a real GPIO once the
// actuator and drive stage are chosen; -1 keeps the bell code inert.
// Candidates, avoiding strapping pins (0, 3, 45, 46) and UART0 (43, 44):
// 17, 18, 21, 38, 47, 48.
#define PIN_BELL (-1)

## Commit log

2026-08-16 V1: Claude Code desk mascot firmware
    An ESP32-S3 board in a 3D-printed shell of the Claude mascot, showing what
    Claude Code is doing as an animated pixel-art face.
    Firmware:
    - Pixel-grid face renderer straight on esp_lcd, no LVGL. Parametric eyes
    quantised to a grid, dirty-span redraw, per-colour DMA buffers. 62 fps at
    under 5% of the frame budget.
    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
2026-08-16 Add swipeable screens: usage gauge and stats
    Vertical swipes move between three screens; horizontal swipes still change
    the face's style. Which axis is which is a setting, since the touch
    controller's orientation is not confirmed across panels.
    The gauge shows time through Anthropic's rolling limit window and the
    wall-clock time it resets. It measures time rather than consumption, and
    labels itself accordingly: no hook reports quota usage, and StopFailure's
    rate_limit only fires once the limit has already been hit. The window itself
    is exact, derived from the prompt events the board already receives, and
    survives a reboot.
    Supporting work:
    - A 3x5 pixel font, scaled by whole numbers so tex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
    [config.cpp, face.cpp, main.cpp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]
2026-08-16 Show the real five-hour limit, not an estimate
    The gauge was timing the window from the first prompt the board happened to
    see, so it read nearly a full window when the real one was two hours from
    resetting. It now shows the actual figures.
    Claude Code exposes rate_limits.five_hour.used_percentage and .resets_at in
    the status line's JSON. No hook payload carries them -- StopFailure's
    rate_limit only fires once the limit has already been hit. So tools/statusline.py
    forwards them to POST /limits and prints an ordinary status line; gen_hooks.py
    emits its config alongside the hooks.
    The POST is spawned detached: Claude Code cancels an in-flight status line
    script when a new update arrives, and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
    [net.cpp]
2026-08-16 Draw the usage gauge as a real circle
    The blocky ring was hard to read, which defeats the point of a dial.
    The earlier objection to a smooth arc -- that testing every cell in the
    bounding box means 1600 SPI transactions -- confused two different costs.
    Testing pixels is a few thousand float operations and is free. Only the
    transactions matter. Scanning each row and coalescing runs of identical colour
    gives one rectangle per run: a few hundred transactions for the whole ring,
    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
2026-08-16 Gauge legibility, and a staleness counter
    Visual: the unfilled track was 45% of the background, close enough to black
    that the two were hard to separate -- which is the one distinction a dial
    exists to make. Now 70%. The ring moves down to sit better on the panel, and
    both labels go up a size.
    Diagnostic: device.limit_age_s reports seconds since the host last sent
    figures, or -1 if it never has. The status line should report at least once a
    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
2026-08-16 Add the weekly limit screen; bigger labels, lower layout
    Vertical swipe now cycles face, five-hour, weekly, stats.
    Weekly reads rate_limits.seven_day from the same status line source. It drops
    the line underneath the ring: the percentage is the whole point there, and a
    seven-day countdown is not something anyone reads off a desk ornament.
    Layout: everything moves down again and both labels go up to scale 4.
    No credits screen. Claude Code exposes no credit or balance figure anywhere --
    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
2026-08-16 Custom face: storage, rendering and endpoints
    A sixth style, drawn by the user rather than built in. 24x28 cells at 10
    screen pixels is exactly 240x280, so the grid maps onto the panel with no
    scaling and no rounding. Two bits per cell: background, black, white -- white
    because the built-in faces use it for lens glints.
    Two frames, resting and blink. A static custom face would sit dead next to the
    built-in ones, which all blink, and one extra frame is the cheapest animation
    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
2026-08-16 Four custom face slots instead of one
    Swiping between a single user-drawn face and five built-ins was thin. Four
    slots, 336 bytes each, one NVS key per slot so saving one face does not
    rewrite the others.
    Empty slots are skipped when swiping rather than shown as blank screens, so
    the rotation is only ever as long as the number of faces that exist. The skip
    loop is bounded by the roster length, so an entirely empty set cannot spin.
    /api/face takes a slot parameter on both verbs and reports which slots are
    occupied. /api/config carries the same as custom_faces.
    Also: style changes now log from the render task rather than the key handler,
    which read the value before the deferred change had b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
    [config.cpp, face.cpp, main.cpp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]
2026-08-16 Pixel face editor on the settings page
    Four slots, two frames each, three inks. 24x28 cells at ten screen pixels is
    exactly the panel, so the canvas is one-to-one with the device and the editor
    draws on the board's real field colour rather than a neutral grey.
    Drag painting interpolates between pointer samples, which arrive far apart on
    a fast swipe, so a quick stroke paints a continuous line instead of a dotted
    one. Leaving and re-entering the canvas does not draw a joining line.
    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
2026-08-16 Long buzz for bad news, and per-cue sound choice
    Not everyone wants to build a mechanical bell, so the buzzer now covers
    everything on its own. Three cues -- blocked, error, finished -- each with its
    own choice of striker, buzzer, both or nothing.
    The buzzer has two shapes rather than two pitches: a short rising double chirp
    for good news, one long tone for bad. Shape carries further than pitch, and
    the point is to be readable with your back to the desk. The long buzz does not
    repeat; that would be alarming rather than informative.
    This replaced three booleans with three enums, which shifts every later index
    in the settings table -- and values are stored in NVS by index, so each
    setting wo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
    [bell.cpp, config.cpp, face.cpp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]
2026-08-16 Fix leftovers around the gauge percentage
    The number inside the ring erased a fixed 112px column, but four characters at
    that size are 120px wide -- so 100%, IDLE or a fallback countdown left
    fragments on both sides that no later erase could reach.
    The erase is now sized from the wider of the outgoing and incoming strings and
    clamped to the inner chord, and long values drop a size rather than crowding
    the circle. The erase band itself is fixed rather than tracking the text
    height: a band that moved with the size would leave the taller version's rows
    behind, which is the same bug one level down.
    Documented that the status line only runs in the CLI. The desktop app has no
    status bar and neve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
2026-08-16 Windows support for the status line
    The hooks were already portable -- exec form, no shell, curl everywhere. The
    status line was not: statusLine has no args field, so it always runs through a
    shell, and a different one per platform.
    Adds a PowerShell twin of the Python script. It exists because Python is not
    dependable on Windows -- usually python rather than python3, with the Store
    stub hijacking the name -- while PowerShell always is, and has ConvertFrom-Json
    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
2026-08-16 Catch a punctual but frozen usage percentage
    An idle Claude Code session reports on its timer while its rate-limit snapshot
    never moves: those figures refresh from API responses, and an idle session
    makes none. Parked beside the desktop app it forwards the same number forever.
    The gauge looked live -- reports arriving every 60s, age resetting -- while the
    percentage was hours old, which is worse than showing nothing.
    The board can tell, because the hooks keep reporting prompts. Five prompts with
    no change in the percentage is not plausible for a five-hour budget, so the
    gauge labels itself PCT STALE and /api/config exposes limit_suspect.
    Documented the real constraint rather than the one I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
    [net.cpp]
2026-08-16 Animate drawn faces by moving them
    A bitmap cannot change shape, so the custom faces only blinked while the
    built-in ones swept, drooped and bounced. But a bitmap can move, and moving
    turns out to carry most of the expression: the whole drawing translates within
    the panel and the background fills what the shift vacates. Drawn faces now get
    the same mood vocabulary as the parametric ones with no extra frames to draw.
    Offsets are whole cells. The art is ten-pixel blocks, so ten-pixel steps keep
    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
2026-08-23 Add CAD, schematic, BOM and photos; rebuild the README around them
    The repo was firmware and prose only. Everything needed to actually build the
    thing lived outside it: the printable parts, the wiring, the parts list, and any
    picture of what it looks like when it works.
    CAD/ carries the front and back shells, monitor hook, bell plate, bell cam and
    USB-C plate, as 3MF and STEP. Hardware/ carries the schematic and a bill of
    materials with Farnell and Newark order codes. images/ carries the build and
    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
    [Bell Cam 2.3mf, Bell Cam 2.step, Bell Plate V1 (1).3mf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]
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

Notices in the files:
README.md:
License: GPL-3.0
